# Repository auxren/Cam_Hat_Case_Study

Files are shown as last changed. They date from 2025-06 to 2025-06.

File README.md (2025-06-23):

# Raspberry Pi Zero 2 W Camera Module Daughterboard

## Overview

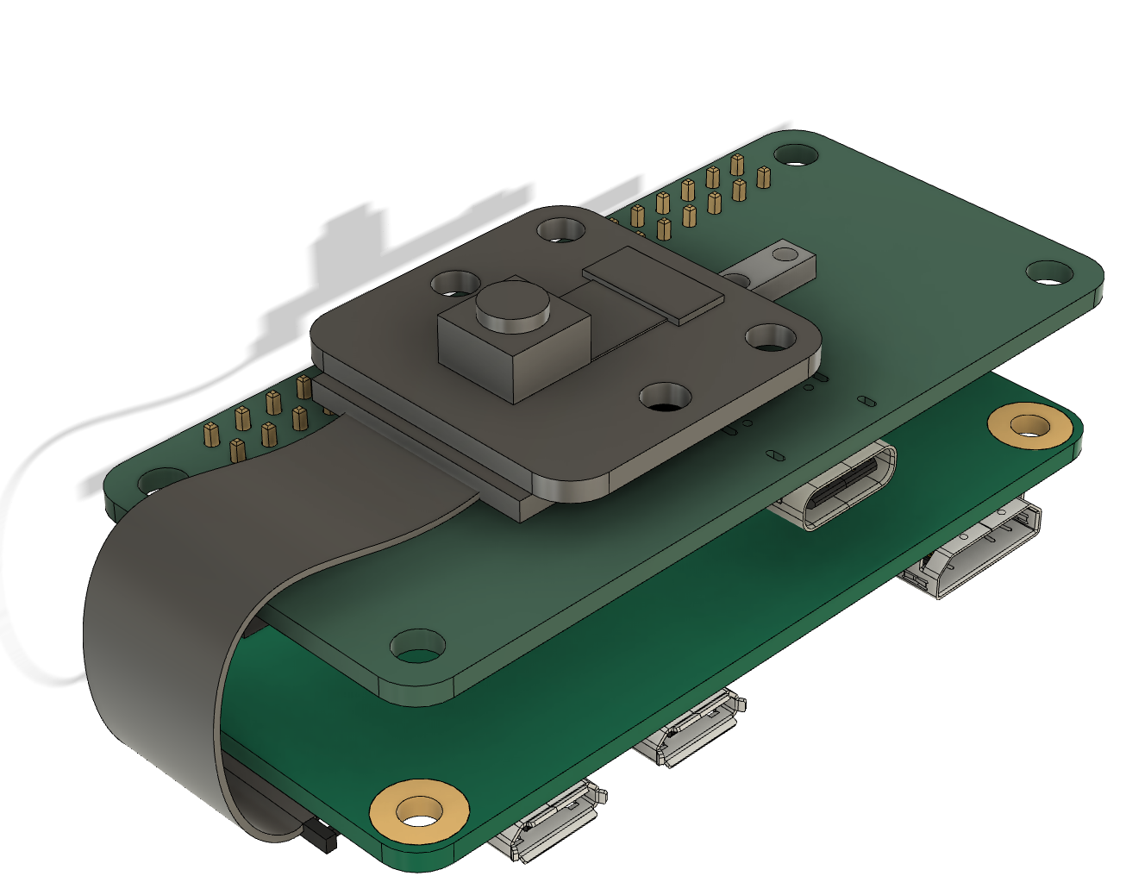
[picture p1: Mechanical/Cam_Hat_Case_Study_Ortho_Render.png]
RENDER


This was from a 72hr design challenge / case study for an interview for a Senior Electrical Engineering Role.

## Requirements

- Camera Module: Integrate the IMX219 camera module (IQL-IMX219/FF).
= Motion Detection: Integrate a suitable PIR motion sensor to detect motion to trigger the
camera.
- Lighting Adjustment: Integrate a suitable ambient light sensor that will be later used to
adjust camera settings based on lighting conditions.
- Power Supply: Design a power supply circuit to ensure stable operation. Choose and
justify the power management components used. Use at least one switching regulator in
your design.
- Form Factor: Ensure the daughter board fits within the dimensions of the Raspberry Pi
Zero 2 W (65mm x 30mm).
- Interconnection: The daughter board will connect to the Raspberry Pi Zero 2 W through
the GPIO header. All components, including the camera module, PIR sensor, and
ambient light sensor, must be placed on the daughter board. Additionally, include an FFC
connector on the edge of the daughter board to allow the user to connect an FFC cable
between the daughter board and the CSI interface of the Raspberry Pi Zero W.
- Power Supply: Assume the Raspberry Pi will be powered with a 5V 3A DC power
supply. Consider power losses and efficiencies.

## Features

- IMX219 camera integration via CSI interface  
- Ambient light sensor for lighting-aware imaging  
- PIR motion sensor to trigger camera events  
- Switching regulator-based power supply for high efficiency  
- Direct connection to the Raspberry Pi via GPIO and FFC  
- Test points and layout considerations for testability

## System Requirements

| Component | Specification |
|---|---|
| Camera Module | IMX219 (IQL-IMX219/FF) |
| PIR Sensor | Selected for compact form factor and reliable motion detection |
| Ambient Light Sensor | Tuned for visible spectrum and camera exposure control |
| Power Input | 5V 3A DC (via Raspberry Pi USB input) |
| Form Factor | 65mm x 30mm (same as Raspberry Pi Zero 2 W) |
| Interfaces | GPIO header and FFC connector |

## Deliverables

- ✅ Schematic Design (KiCad project and PDF)
- ✅ PCB Layout (KiCad, Gerber files, and 3D model)
- ✅ Bill of Materials (BOM) with part numbers and specifications
- ✅ Power Supply Design Document (efficiency and regulator choice justification)
- ✅ Design Decision Documentation (component selection and rationale)

## Folder Structure

<pre> <code>
├── Cam_Hat_Case_Study_Oren_Levy_Presentation.key -- Case study presentation. Open in Apple Keynote.
├── Cam_Hat_Case_Study_Oren_Levy_Presentation.pdf
├── Firmware:Software
│   └── TfH_Case_Study_FW_TODO.numbers -- Document for tracking items FW should be mindful of. Open in Apple Numbers.
├── Hardware
│   ├── Block Diagram
│   │   └── Cam_Hat_Case_Study_Block_Diagram.png -- High level block diagram
│   ├── BOMs
│   │   └── Cam_Hat_Case_Study_PCB_Assembly_BOM.csv -- Assembly BOM
│   ├── Datasheets -- Datasheet PDFs for referencing
│   ├── Pinout Docs
│   │   └── Cam_Hat_Case_Study_Pinout_Tracker.numbers -- Document for tracking pinouts and net names. Open in Apple Numbers.
│   ├── Power
│   │   └── CamHat_Power_Tracker.numbers -- Power calculator document. Open in Apple Numbers.
│   ├── Schematic
│   │   └── Cam_Hat_Case_Study_Schematic.pdf
│   └── TfH_Case_Study -- KiCad Project
├── LICENSE
├── Mechanical
│   ├── Cam_Hat_Case_Study_Model.STEP -- Model of full "product"
│   ├── Cam_Hat_Case_Study_Ortho_Render.png
│   ├── Cam_Hat_Case_Study_Render_Case_Ortho.png
│   ├── Cam_Hat_Case_Study_Side_Render.png
│   └── Subassemblies  -- Folder with dxf and stp files used for assembly
└── README.md
</code> </pre>

## Block Diagram
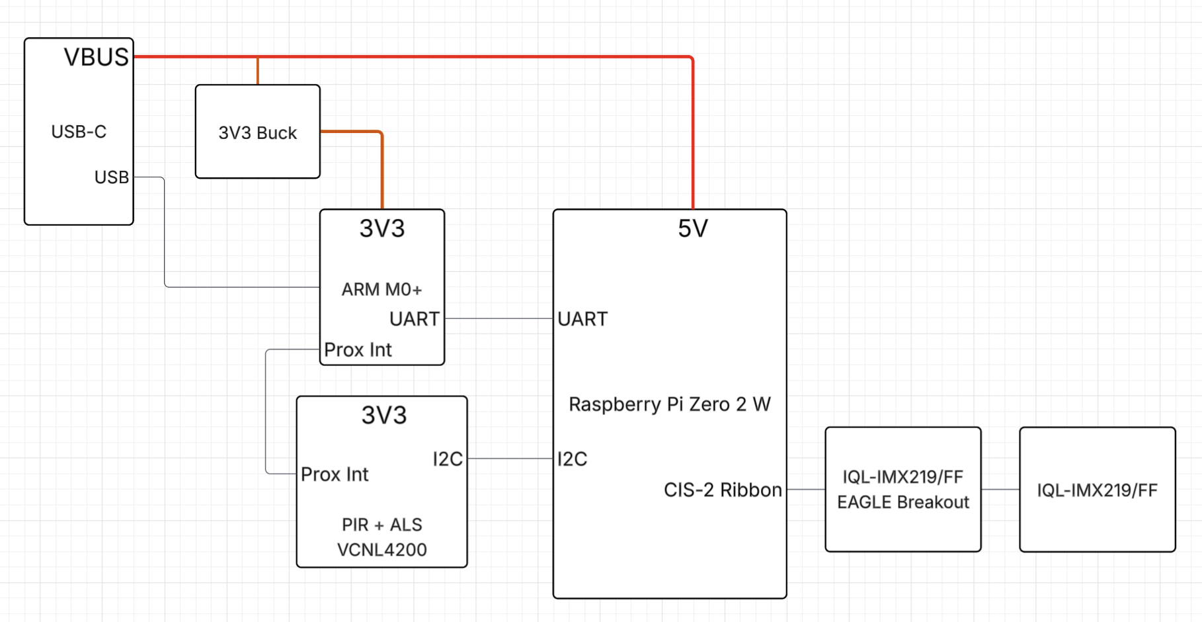
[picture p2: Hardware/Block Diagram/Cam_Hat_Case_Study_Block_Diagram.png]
BLOCK DIAGRAM


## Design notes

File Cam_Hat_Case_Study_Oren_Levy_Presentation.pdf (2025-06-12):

# Tools For Humanity Camera Hat Case Study

Prepared by Oren Levy

## Camera Hat | Intro & Renders

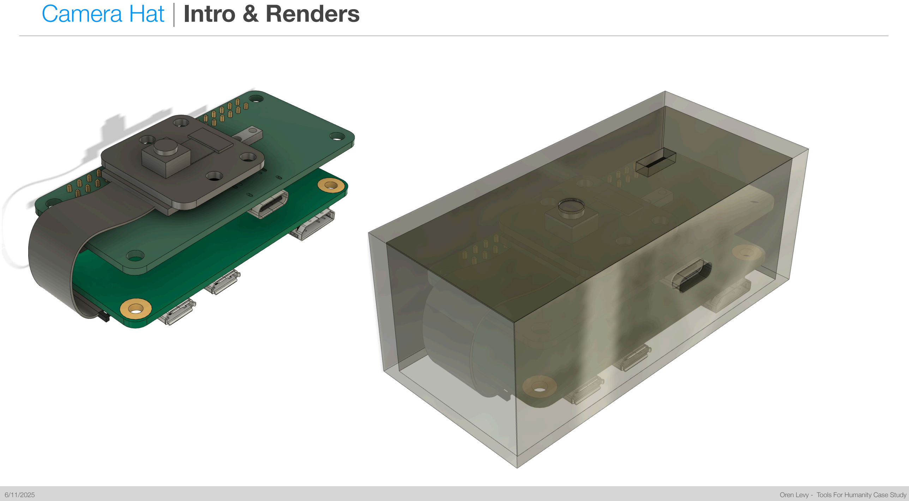
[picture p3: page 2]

6/11/2025 | Oren Levy - Tools For Humanity Case Study

## Camera Hat | Block Diagram

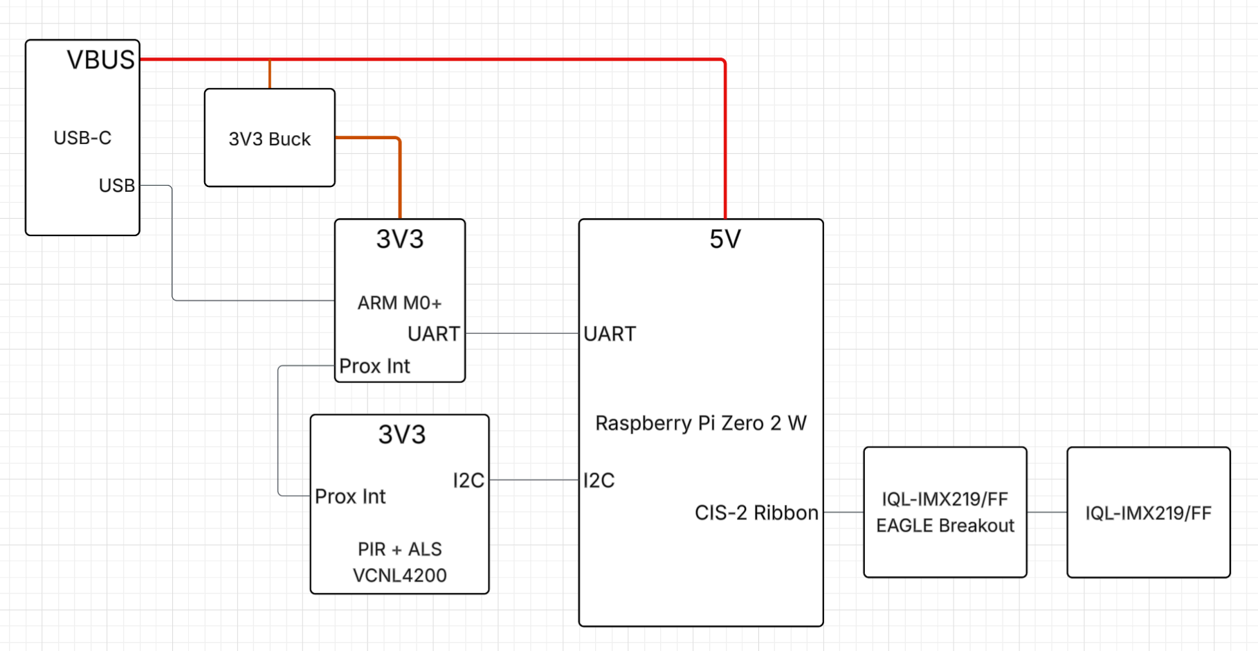
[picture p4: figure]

## Camera Hat | Features

- Arm M0+ incorporated
- Allows for 25mW standby consumption (Instead of 525mW) in conjunction with a load switch that disconnects the Raspberry Pi
- When motion is detected, an interrupt wakes up the MCU, which closes the load switch and boots (~6s). By using a longer distance (1.5 meter) proximity sensor, 6 seconds should be able time for the user to approach and position themselves in front of the camera.
- USB-C connector incorporated for application of power
- FATP test, debug, and firmware development to be done using USB-C connector
- Enumerates CLI, tunneling into Raspberry Pi via UART
- Disabled at end of FATP before packaging
- Vishay VCNL4200 used for Proximity and Ambient Light Sensing
- Initial research went into the recommended PIR sensors (slide). Cost and integration when incorporating an ALS grew in complexity. When comparing to a unit such as the VCNL4200 that combines the prox and ALS into a monolithic package (slide), the VCNL4200 won from a power, cost, and FATP integration point of view.
- A complex power architecture was conceived for powering the IQL-IMX219/FF. Upon further research, the IQL-IMX219/FF/Eagle (https://www.imagequalitylabs.com/digital-camera-modules/sony-imx219-8mp-ff-raspberry-pi-camera) was found. It adapts the IQL-IMX219/FF to the Raspberry Pi Zero 2 W’s CIS-2 ribbon connection. This alleviated any need for power rail generation, MIPI routing, and added complexity to the design; none of the camera signals touch the camera hat PCB.
- The IQL-IMX219/FF/Eagle (https://www.imagequalitylabs.com/digital-camera-modules/sony-imx219-8mp-ff-raspberry-pi-camera) mounts to the inside of the enclosure, the Camera Hat board goes on top, then the flex connects to the RPi, which gets plugged into the Camera Hat board.
- This left the necessity to generate a 3V3 rail via a buck converter, due to the case study’s requirements.
- The Raspberry Pi itself generates 3V3 with sufficient current to power the VCNL4200
- Factory testing at a PCBA level is enabled by TPs only on the bottom of the board, which only has the VCNL4200 as the only component, for easy fixturing in a bed of nails

## Camera Hat | Documents And Links

- Everything is shared on GitHub at: https://github.com/auxren/Cam_Hat_Case_Study/
- Schematic (https://github.com/auxren/Cam_Hat_Case_Study/blob/main/Hardware/Schematic/Cam_Hat_Case_Study_Schematic.pdf)
- KiCad Project (https://github.com/auxren/Cam_Hat_Case_Study/tree/main/Hardware/TfH_Case_Study)
- BOM (https://github.com/auxren/Cam_Hat_Case_Study/blob/main/Hardware/BOMs/Cam_Hat_Case_Study_PCB_Assembly_BOM.csv)
- Power Calculator (https://github.com/auxren/Cam_Hat_Case_Study/blob/main/Hardware/Power/CamHat_Power_Tracker.numbers)

# Design Considerations

## Camera Hat | PIR Sensor: Downselection

MPN | Manufacturer | Voltage | Current | IO | Range | FOV | Cost | Size | Notes
EKMB1110112 | Panasonic | 2.3-4V

1uA Sleep
1.9uA
Standy
100uA Max
Drive
Digital | 5m | 100° × 90° | $12.22@5
00 | 10.6 x 10.6 x 10.9 | Black
Rectangle
EKMB110711* | Panasonic | 2.3-4V

1uA Sleep
1.9uA
Standy
100uA Max
Drive
Digita | 5m | 100° × 90° | $12.51@5
| | | 00

10.4mm dia
10.9mm tall

White or
Black Dome
IRA-S210ST01 | Murata | 2.7-3.6V | ~6uA | Analog | 3m | 100° × 90° | $1.3@500 | 12 x 7 x 5

Cheaper
because it
doesn’t
include lease.
Analog

## Camera Hat | PIR Vs Combo PIR+ALS: Downselection

MPN | Manufacturer | Voltage | Current | IO | Range | FOV | Cost | Size | Notes
EKMB1110112 | Panasonic | 2.3-4V

1uA Sleep
1.9uA Standy
100uA Max
Digital | 5m | 100° × 90° | $12.22@500 | 10.6 x 10.6 x 10.9

Prox Only
Black
Rectangle
LTR-578ALS-01 | Liteon | 1.7-3.6V

1uA Standby
95uA Prox
110uA ALS

I2C
INT | 10cm | - | $0.42@100 | 3.9 x 2.36 x 1.35

Combo Prox
and ALS
Short
Distance
VCNL4040M3OE | Vishay | 2.5-3.6

300uA + LED
Active
460uA Shut
Down
I2C | 20cm | ~40° | $1.20@500 | 4 x 2 x 1.1

Combo Prox
and ALS
Short
Distance
VCNL4200 | Vishay | 2.5-3.6

0.2uA Sleep
213uA Prox
350uA max +
LED
I2C | 1.5m | ~40° | $1.51@5,000 | 8 x 3 x 1.8 | Combo Prox and ALS

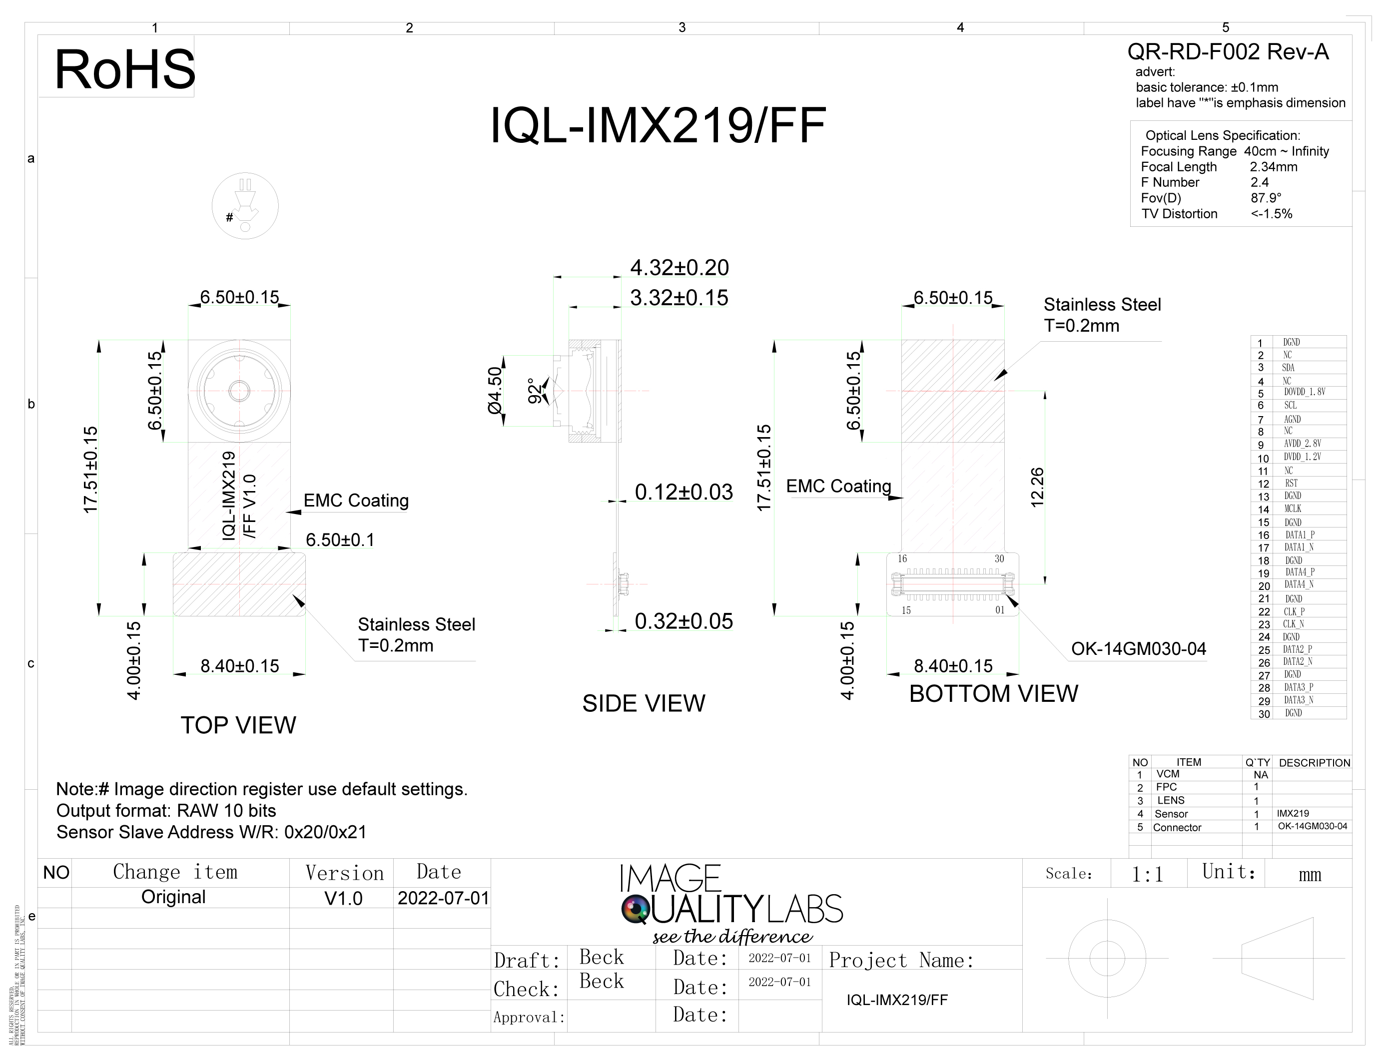
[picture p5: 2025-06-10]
Hardware/Datasheets/IQL-IMX219:FF/666b24bf9f3bf878a5250962_IQL-IMX219-FF-Latest_Drawing.jpg

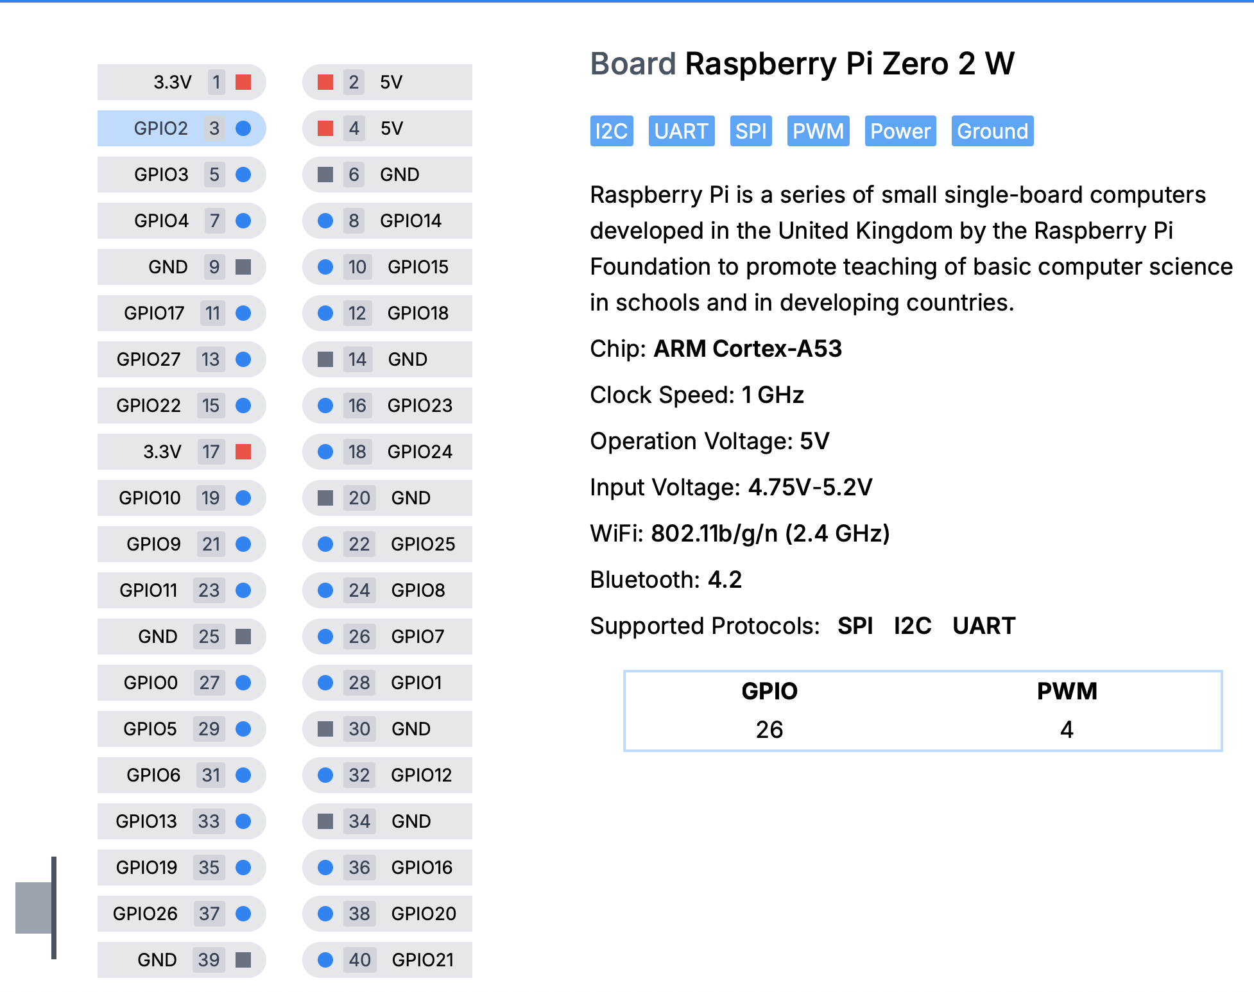
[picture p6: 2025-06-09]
Hardware/Datasheets/RPi Zero 2 W/RPiZero2W Pinout.png

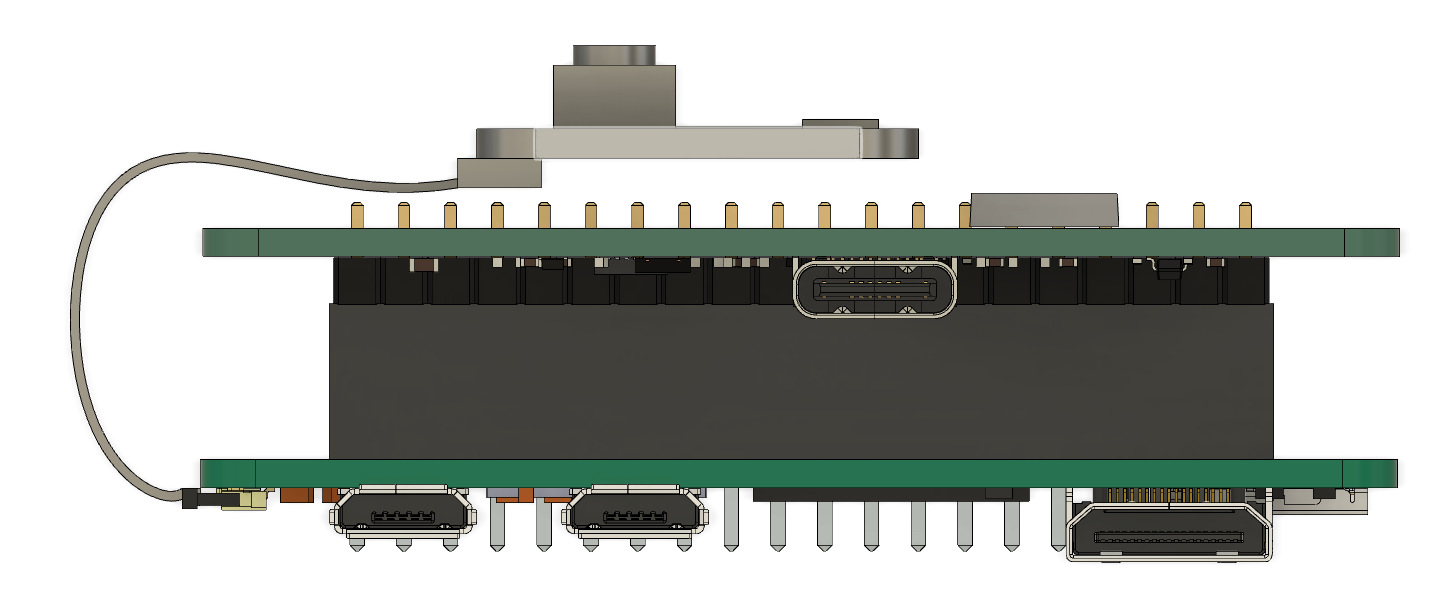
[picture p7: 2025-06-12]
Mechanical/Cam_Hat_Case_Study_Side_Render.png

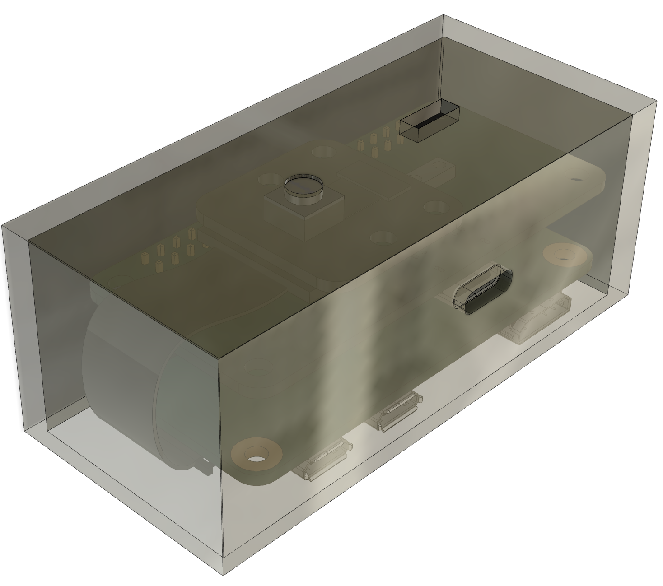
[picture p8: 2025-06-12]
Mechanical/Cam_Hat_Case_Study_Render_Case_Ortho.png

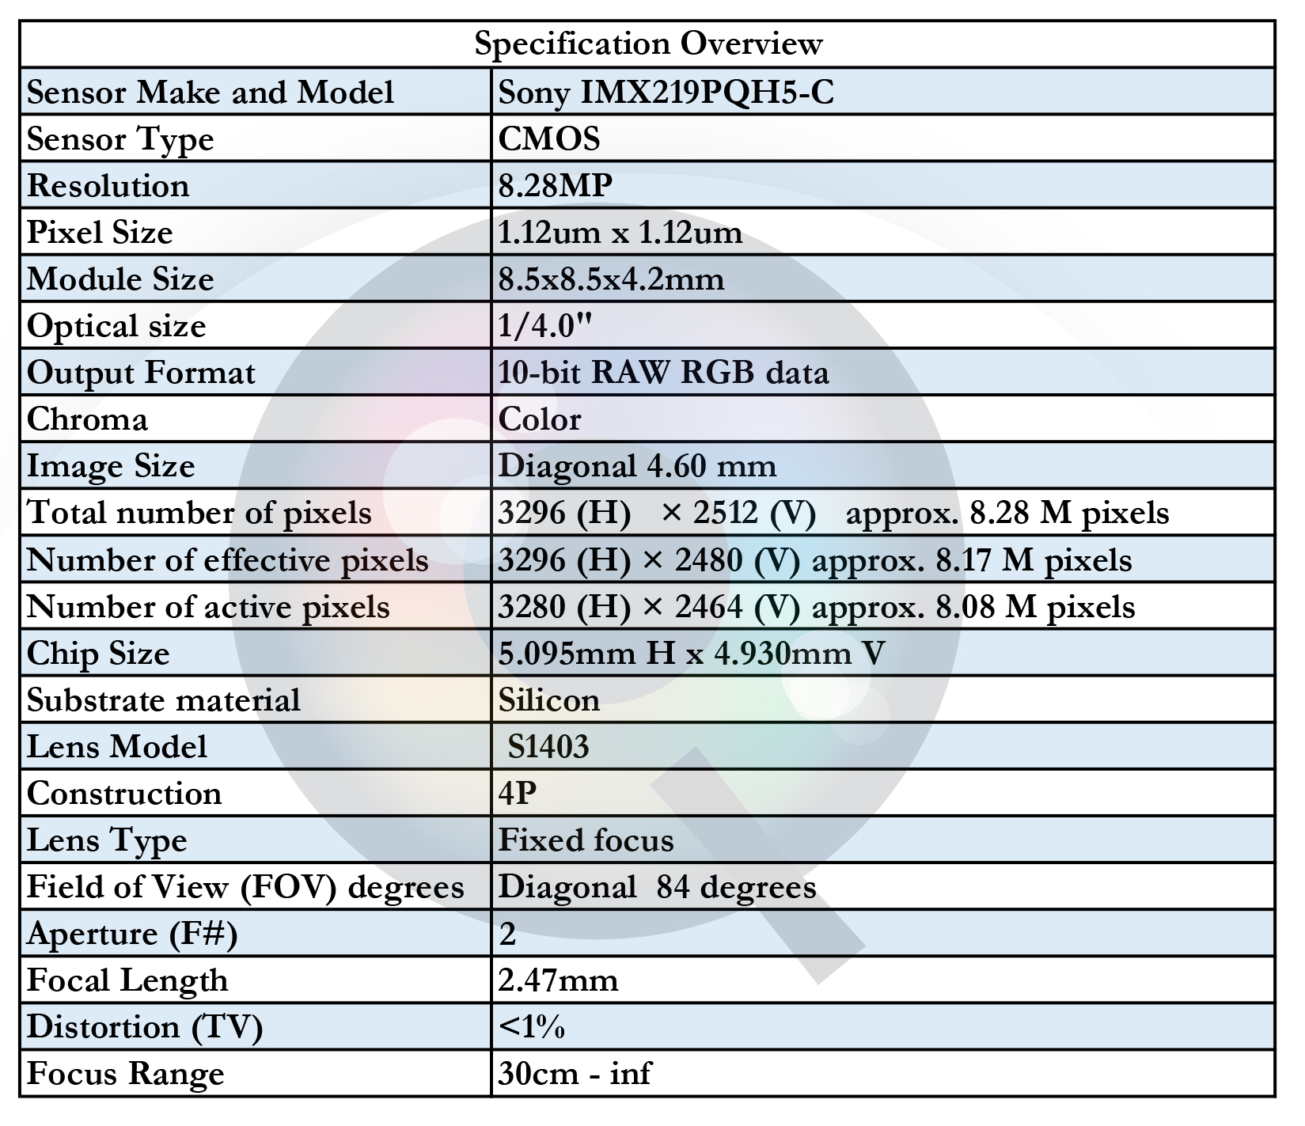
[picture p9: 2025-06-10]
Hardware/Datasheets/IQL-IMX219:FF/68388aef5e7ae0aa4206bc80_643aabf46146708020343a5a_IMX219FF%20Table.jpeg

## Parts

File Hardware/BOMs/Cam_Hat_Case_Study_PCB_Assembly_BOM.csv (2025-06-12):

Reference | Qty | Value | DNP | Footprint | Datasheet | Manufacturer_Name | Manufacturer_Part_Number | Description
C201,C303 | 2 | 22uF |  | Capacitor_SMD:C_0402_1005Metric | ~ | Murata | GRM158R61A226ME15J | Multilayer Ceramic Capacitors MLCC - SMD/SMT 22 uF 10 VDC 20% 0402 X5R
C202 | 1 | 1uF |  | Capacitor_SMD:C_0402_1005Metric | ~ | Kyocera | 04023D105KAT2A
C301,C601,C603 | 3 | 4.7uF |  | Capacitor_SMD:C_0402_1005Metric | ~ | Kyocera | 0402YD475MAT2A | Multilayer Ceramic Capacitors MLCC - SMD/SMT KGM05CR51C475MH NEW GLOBAL PN 16V 4.7uF A 581-KGM05CR51C475MH
C401 | 1 | 100uF |  | Capacitor_SMD:C_0805 | ~ | Kyocera | 08056D107MAT2A | Multilayer Ceramic Capacitors MLCC - SMD/SMT KGM21AR50J107MU NEW GLOBAL PN 6.3V 100uF A 581-KGM21AR50J107MU
C402 | 1 | 10uF |  | Capacitor_SMD:C_0603_1608Metric | ~ | Kyocera | 0603YD106MAT2A | Multilayer Ceramic Capacitors MLCC - SMD/SMT KGM15CR51C106MT NEW GLOBAL PN A 581-KGM15CR51C106MT
C502 | 1 | 2.2uF |  | Capacitor_SMD:C_0402_1005Metric | ~ | Kyocera | 0402ZD225MAT2A | Multilayer Ceramic Capacitors MLCC - SMD/SMT KGM05AR51A225MH NEW GLOBAL PN 10V 2.2uF A 581-KGM05AR51A225MH
C602,C604,C403,C501 | 4 | 100nF |  | Capacitor_SMD:C_0402_1005Metric | ~ | Kyocera | 0402X7R104KT7AT | Multilayer Ceramic Capacitors MLCC - SMD/SMT 16V 0.1uF X7R 10%
D601 | 1 | PESD5V0S1UL |  | Diode_SMD:D_SOD-882 | https://assets.nexperia.com/documents/data-sheet/PESD5V0S1UL.pdf | Nexperia | PESD5V0S1UL | Unidirectional ESD protection diode, 5V, SOD-882
FB601,FB602 | 2 | FerriteBead |  | Capacitor_SMD:C_0402_1005Metric | ~ | TDK | MPZ1005S330HT000 | Ferrite Beads 33OHM 3a 22mohms 1005 FERRITE CHIP
IC201 | 1 | TPS22969DNYT |  | TPS22969DNYT | http://www.ti.com/lit/gpn/TPS22969 | Texas Instruments | TPS22969DNYT | 5.5V, 6A, 4.4m Load Switch with Quick Output Discharge
IC601 | 1 | ATSAMD11D14A-MUT |  | Footprints:QFN50P400X400X90-25N-D | https://datasheet.datasheetarchive.com/originals/distributors/DKDS41/DSANUWW0026705.pdf | Microchip | ATSAMD11D14A-MUT | ARM Microcontrollers - MCU IC MCU 32 BIT 16KB Flash 24QFN
J601 | 1 | USB_C_Receptacle_USB2.0_14P |  | Connector_USB:USB_C_Receptacle_GCT_USB4105-xx-A_16P_TopMnt_Horizontal | https://www.usb.org/sites/default/files/documents/usb_type-c.zip | Same Sky | UJ32-C-H-G-SMT-6-P24-TR | USB Connectors Type C, 3.2, Horizontal, Gold Flash, Surface Mount, 24 pin, T&R
L301 | 1 | 1uH |  | Inductor_SMD:L2x1_6 | ~ | Murata | LQM2HPN1R0MG0 | 1.0 µH, 1.9 A Isat, 33 mΩ DCR
Q501 | 1 | Si2319CDS |  | Package_TO_SOT_SMD:SOT-23 | http://www.vishay.com/docs/66709/si2319cd.pdf | Vishay | Si2319CDS | -4.4A Id, -40V Vds, P-Channel MOSFET, SOT-23
R302,R310,R312,R314,R402,R403,R405 | 7 | 0Ω 0402 |  | Resistor_SMD:R_0402_1005Metric | ~ | Vishay | CRCW04020000Z0EDC | Thick Film Resistors - SMD 1/16watt 0ohm Commercial Use
R304 | 1 | 453k |  | Resistor_SMD:R_0402_1005Metric | ~ | Vishay | CRCW0402453KFKTD | Thick Film Resistors - SMD 1/16watt 453Kohms 1%
R305 | 1 | 100k |  | Resistor_SMD:R_0402_1005Metric | ~ | Panasonic | ERJ-S02J104X | Thick Film Resistors - SMD 0402 100Kohms 1%
R319 | 1 | 0Ω 0402 | DNP | Resistor_SMD:R_0402_1005Metric | ~ | Vishay | CRCW04020000Z0EDC | Thick Film Resistors - SMD 1/16watt 0ohm Commercial Use
R401,R404 | 2 | 3.3k 0402 |  | Resistor_SMD:R_0402_1005Metric | ~ | Yageo | RC0402FR-7D3K3L | Thick Film Resistors - SMD 0402 3.3Kohms 1%
R501 | 1 | 2.7k 0402 |  | Resistor_SMD:R_0402_1005Metric | ~ | Panasonic | ERA-2ARC272X | Thin Film Resistors - SMD 0402 Thin film chip resistor
R502 | 1 | 1k 0402 |  | Resistor_SMD:R_0402_1005Metric | ~ | SEI Stackpole | RNCE0402BTE1K00 | Thin Film Resistors - SMD 1KOhms 0402 25ppm 1/16W 50V 0.1% Hi Temp/Stability
R601,R602 | 2 | 5.1k 0402 |  | Resistor_SMD:R_0402_1005Metric | ~ | Kamaya | RMC1/16SK5111FTH | Thick Film Resistors - SMD 0402 5K11 1%
U301 | 1 | TLV62568ADRL |  | Package_TO_SOT_SMD:SOT-563 | https://www.ti.com/lit/gpn/tlv62568a | Texas Instruments | TLV62568ADRL | High Efficiency Synchronous Buck Converter with forced PWM, Adjustable Output 0.6V-5.5V, 1A, SOT-563-6
U401 | 1 | Raspberry Pi Zero 2 W |  | Connector_PinHeader_2.54mm:PinHeader_2x20_P2.54mm_Vertical |  | Molex | 90131-0780 | Headers & Wire Housings 2.54MM CGRIDIII HDR 40P VERT DR SEL AU
U501 | 1 | VCNL4200 |  | Footprints:SMT_L4200_VIS | VCNL4200 | Vishay | VCNL4200 | High Sensitivity Long Distance Proximity and Ambient Light Sensor With I2C Interface
U601 | 1 | TPD4E05U06DQA |  | Package_SON:USON-10_2.5x1.0mm_P0.5mm | https://www.ti.com/lit/ds/symlink/tpd4e05u06.pdf | Texas Instruments | TPD4E05U06DQA | 4-Channel ESD Protection for Super-Speed USB 3.0 Interface, USON-10

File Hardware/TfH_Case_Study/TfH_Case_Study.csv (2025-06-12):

Reference | Qty | Value | DNP | Exclude from BOM | Exclude from Board | Footprint | Datasheet | Manufacturer_Name | Manufacturer_Part_Number | Mouser Part Number | Description
C201,C303 | 2 | 22uF |  |  |  | Capacitor_SMD:C_0402_1005Metric | ~
C202 | 1 | 1uF |  |  |  | Capacitor_SMD:C_0402_1005Metric | ~
C301,C601,C603 | 3 | 4.7uF |  |  |  | Capacitor_SMD:C_0402_1005Metric | ~ |  |  |  | Unpolarized capacitor
C401 | 1 | 100uF |  |  |  | Capacitor_SMD:C_0603_1608Metric | ~ |  |  |  | Unpolarized capacitor, small symbol
C402 | 1 | 10uF |  |  |  | Capacitor_SMD:C_0603_1608Metric | ~ |  |  |  | Unpolarized capacitor, small symbol
C403,C501 | 2 | 0.1uF |  |  |  | Capacitor_SMD:C_0402_1005Metric | ~
C502 | 1 | 2.2uF |  |  |  | Capacitor_SMD:C_0402_1005Metric | ~
C602,C604 | 2 | 100nF |  |  |  | Capacitor_SMD:C_0402_1005Metric | ~ |  |  |  | Unpolarized capacitor
D601 | 1 | PESD5V0S1UL |  |  |  | Diode_SMD:D_SOD-882 | https://assets.nexperia.com/documents/data-sheet/PESD5V0S1UL.pdf |  |  |  | Unidirectional ESD protection diode, 5V, SOD-882
FB601,FB602 | 2 | FerriteBead |  |  |  | Capacitor_SMD:C_0402_1005Metric | ~
H1,H2,H4,H5 | 4 | MountingHole_Pad |  | Excluded from BOM |  | MountingHole:MountingHole_3.2mm_M3_DIN965_Pad | ~ |  |  |  | Mounting Hole with connection
IC201 | 1 | TPS22969DNYT |  |  |  | TPS22969DNYT | http://www.ti.com/lit/gpn/TPS22969 | Texas Instruments | TPS22969DNYT | 595-TPS22969DNYT | 5.5V, 6A, 4.4m Load Switch with Quick Output Discharge
IC601 | 1 | ATSAMD11D14A-MUT |  |  |  | Footprints:QFN50P400X400X90-25N-D | https://datasheet.datasheetarchive.com/originals/distributors/DKDS41/DSANUWW0026705.pdf | Microchip | ATSAMD11D14A-MUT | 556-ATSAMD11D14A-MUT | ARM Microcontrollers - MCU IC MCU 32 BIT 16KB Flash 24QFN
J601 | 1 | USB_C_Receptacle_USB2.0_14P |  |  |  | Connector_USB:USB_C_Receptacle_GCT_USB4105-xx-A_16P_TopMnt_Horizontal | https://www.usb.org/sites/default/files/documents/usb_type-c.zip |  |  |  | USB 2.0-only 14P Type-C Receptacle connector
J602 | 1 | Conn_ARM_JTAG_SWD_10 |  |  |  | Connector_PinHeader_1.00mm:PinHeader_2x05_P1.00mm_Vertical_SMD | http://infocenter.arm.com/help/topic/com.arm.doc.ddi0314h/DDI0314H_coresight_components_trm.pdf |  |  |  | Cortex Debug Connector, standard ARM Cortex-M SWD and JTAG interface
L301 | 1 | 1uH |  |  |  | Capacitor_SMD:C_0402_1005Metric | ~
Q501 | 1 | Si2319CDS |  |  |  | Package_TO_SOT_SMD:SOT-23 | http://www.vishay.com/docs/66709/si2319cd.pdf |  |  |  | -4.4A Id, -40V Vds, P-Channel MOSFET, SOT-23
R302,R310,R312,R314,R402,R403,R405 | 7 | 0 |  |  |  | Capacitor_SMD:C_0402_1005Metric | ~
R304 | 1 | 453k |  |  |  | Capacitor_SMD:C_0402_1005Metric | ~
R305 | 1 | 100k |  |  |  | Capacitor_SMD:C_0402_1005Metric | ~
R319 | 1 | 0 | DNP |  |  | Capacitor_SMD:C_0402_1005Metric | ~
R401,R404 | 2 | 3.3k |  |  |  | Capacitor_SMD:C_0402_1005Metric | ~
R501 | 1 | 2.7k |  |  |  | Resistor_SMD:R_0402_1005Metric | ~ |  |  |  | Resistor, US symbol
R502 | 1 | 1k |  |  |  | Resistor_SMD:R_0402_1005Metric | ~ |  |  |  | Resistor, US symbol
R601,R602 | 2 | 5.1 k |  |  |  | Resistor_SMD:R_0402_1005Metric | ~ |  |  |  | Resistor, US symbol
TP401,TP402,TP403,TP501,TP502,TP503,TP504,TP505,TP506,TP507,TP508,TP509,TP510,TP601,TP602,TP603,TP604,TP605,TP606,TP607,TP608,TP609,TP610 | 23 | TestPoint |  | Excluded from BOM |  | TestPoint:TestPoint_Pad_D1.5mm | ~ |  |  |  | test point
U301 | 1 | TLV62568ADRL |  |  |  | Package_TO_SOT_SMD:SOT-563 | https://www.ti.com/lit/gpn/tlv62568a |  |  |  | High Efficiency Synchronous Buck Converter with forced PWM, Adjustable Output 0.6V-5.5V, 1A, SOT-563-6
U401 | 1 | Raspberry Pi Zero 2 W |  |  |  | Connector_PinHeader_2.54mm:PinHeader_2x20_P2.54mm_Vertical
U501 | 1 | VCNL4200 |  |  |  | Footprints:SMT_L4200_VIS | VCNL4200
U601 | 1 | TPD4E05U06DQA |  |  |  | Package_SON:USON-10_2.5x1.0mm_P0.5mm | https://www.ti.com/lit/ds/symlink/tpd4e05u06.pdf |  |  |  | 4-Channel ESD Protection for Super-Speed USB 3.0 Interface, USON-10

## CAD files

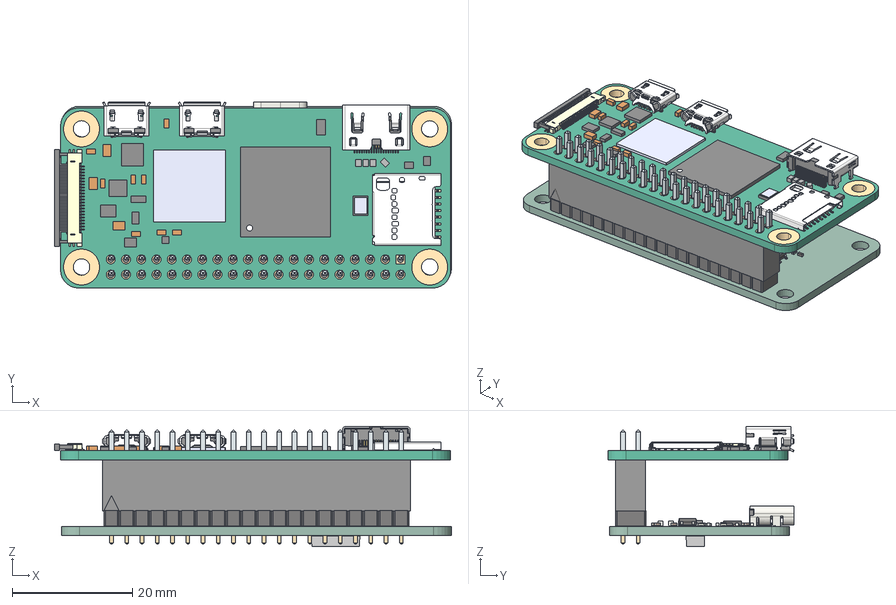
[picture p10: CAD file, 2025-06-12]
Hardware/TfH_Case_Study/Cam_Hat_Case_Study_Model.STEP
66.1 x 31.0 x 20.0 mm
C_0402_1005Metric x 26
R_0402_1005Metric x 4
ThermalPin
PinsArrayLR
PinsArrayTB
PinHeader_2x20_P2.54mm_Vertical
pcb
BCM 2835
ram
Part1^RASPBERRY PI ZERO 2 W
LeadsArray
C_0603_1608Metric x 2
SOT-23
SOT-563
D_SOD-882
USON-10_2.5x1.0mm_P0.5mm
USB_C_Receptacle_GCT_USB4105-xx-A_16P_TopMnt_Horizontal
Prox
TfH_Case_Study_PCB

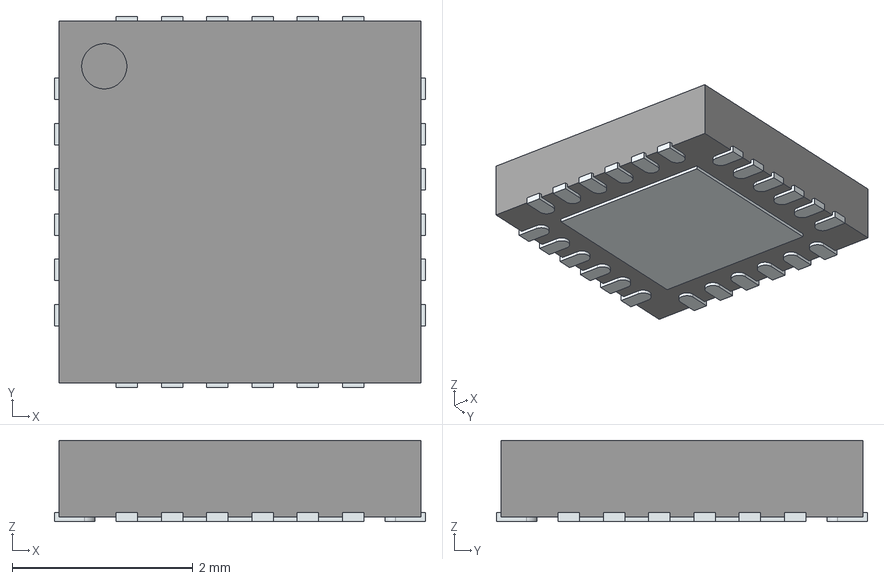
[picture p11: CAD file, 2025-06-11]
Hardware/TfH_Case_Study/Symbols_Footprints/LIB_ATSAMD11D14A-MUT/ATSAMD11D14A-MUT/3D/ATSAMD11D14A-MUT.stp
4.10 x 4.10 x 0.9 mm
ThermalPin
PinsArrayLR
PinsArrayTB

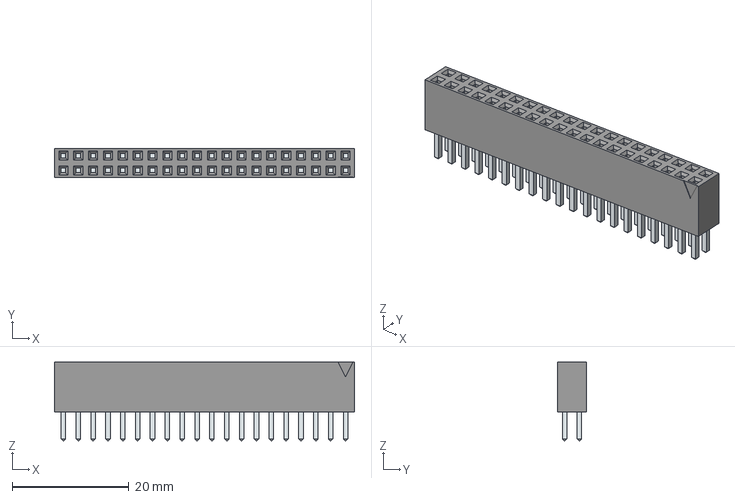
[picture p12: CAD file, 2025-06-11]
Hardware/TfH_Case_Study/Symbols_Footprints/LIB_SSW-120-02-G-D/SSW-120-02-G-D/3D/SSW-120-02-G-D.stp
51.3 x 4.95 x 13.4 mm
LeadsArray

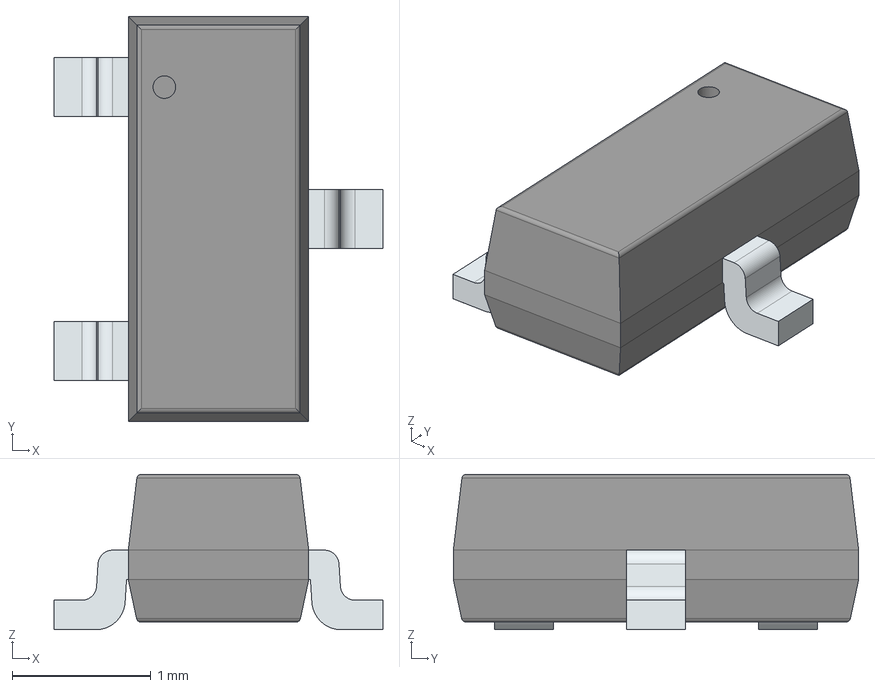
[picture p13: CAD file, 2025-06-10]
Hardware/TfH_Case_Study/Symbols_Footprints/SI2301CDS-T1-BE3.stp
2.37 x 2.92 x 1.12 mm
PinsArrayL
FilletPinR

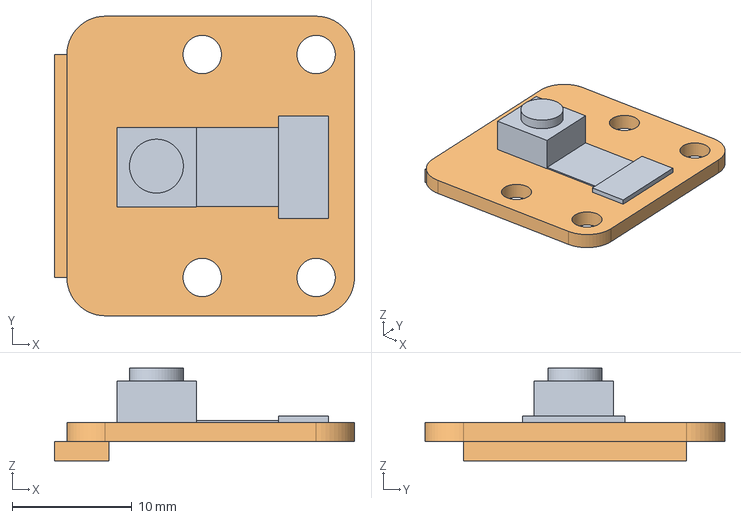
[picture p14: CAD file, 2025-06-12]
Mechanical/Subassemblies/CameraModuleOnEagle.step
25.0 x 25.0 x 7.72 mm

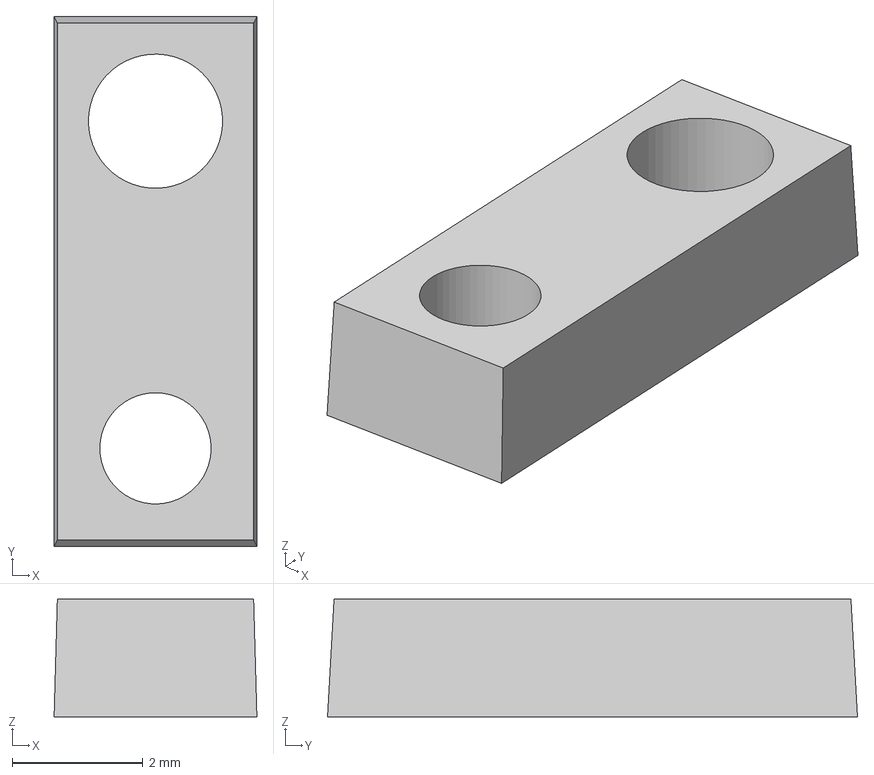
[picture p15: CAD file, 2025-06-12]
Mechanical/Subassemblies/Prox.step
3.10 x 8.10 x 1.80 mm

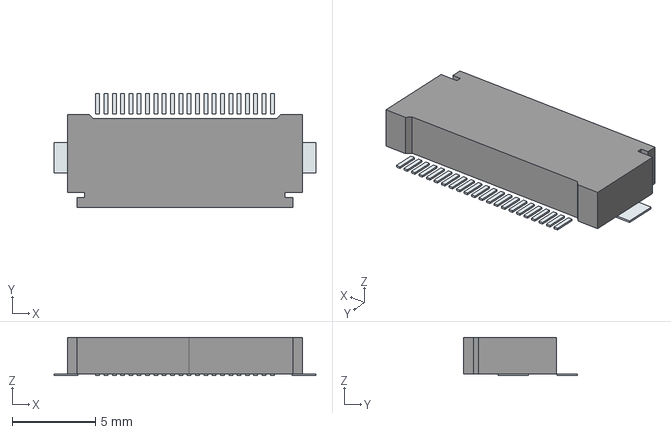
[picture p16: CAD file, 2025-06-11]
Hardware/TfH_Case_Study/Symbols_Footprints/Footprints/FH12-22S-0.5SH_1__98_.stp
15.7 x 6.87 x 2.30 mm
Pins

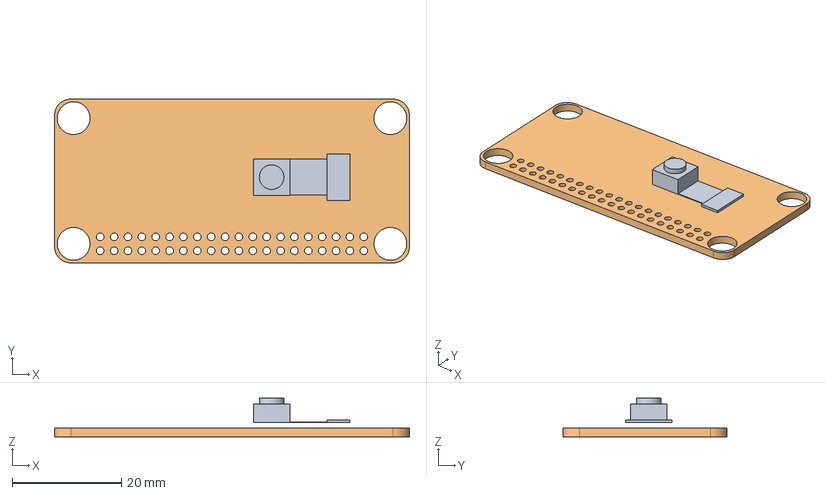
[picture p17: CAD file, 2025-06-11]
Mechanical/Subassemblies/CapHat v3.step
65.0 x 30.0 x 7.12 mm

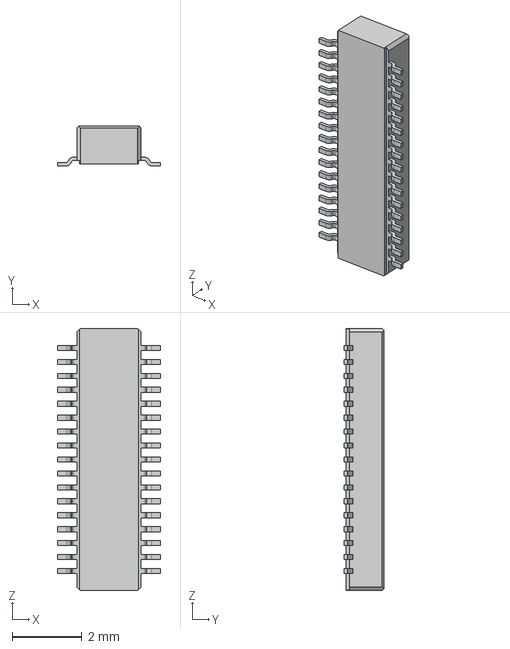
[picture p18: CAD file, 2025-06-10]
Hardware/TfH_Case_Study/Symbols_Footprints/Footprints/DF40C-30DP-0.4V_51_.stp
2.97 x 1.14 x 7.52 mm

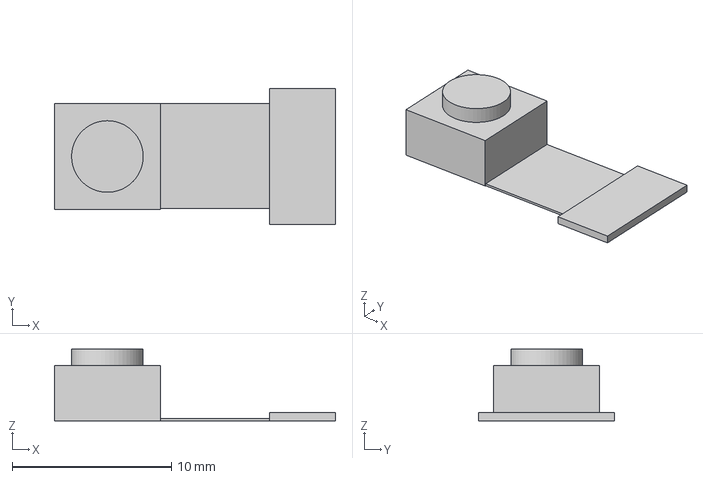
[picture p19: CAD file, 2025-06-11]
Mechanical/Subassemblies/CameraV1.step
17.7 x 8.55 x 4.52 mm

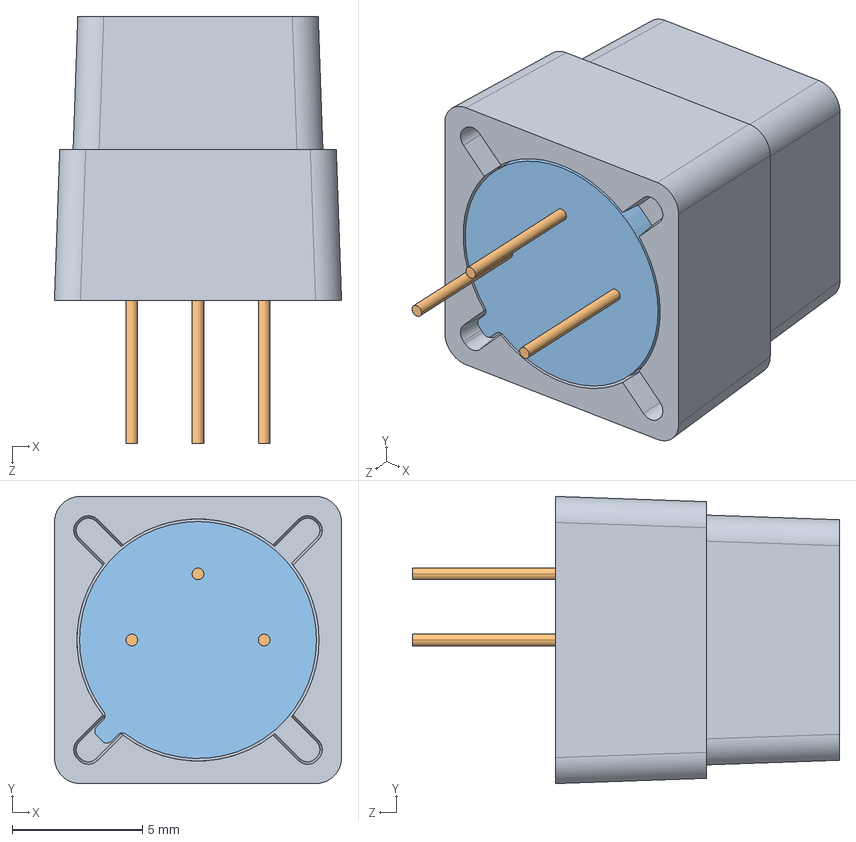
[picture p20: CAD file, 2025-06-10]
Hardware/TfH_Case_Study/Symbols_Footprints/Footprints/EKMB1110112.stp
11.0 x 11.0 x 16.4 mm
(Temp)PaPIRs Flat square type lens_蹬怮椔
stem_蹬怮椔

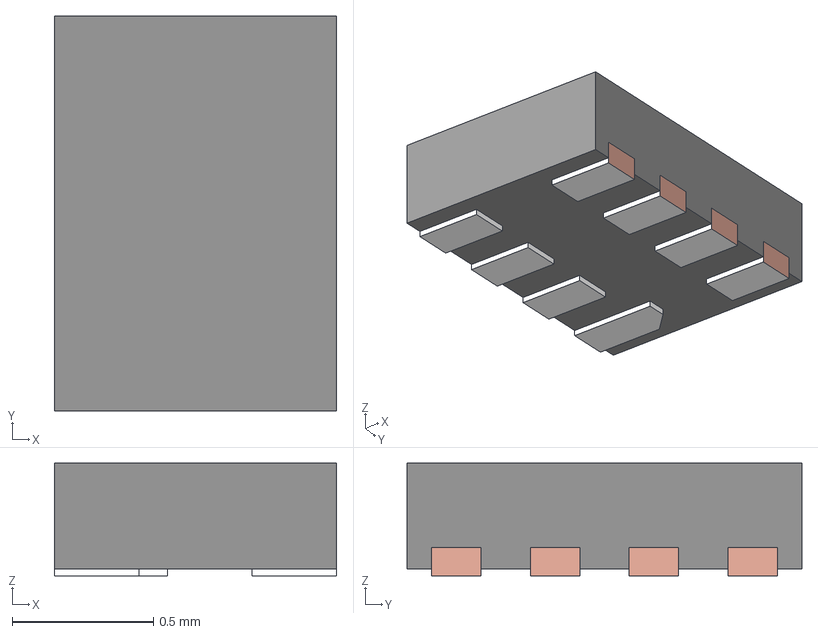
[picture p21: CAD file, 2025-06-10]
Hardware/TfH_Case_Study/Symbols_Footprints/Footprints/PCA9306DQER.stp
1.00 x 1.40 x 0.4 mm
BODY-SON1
FRAME-DQE0008A

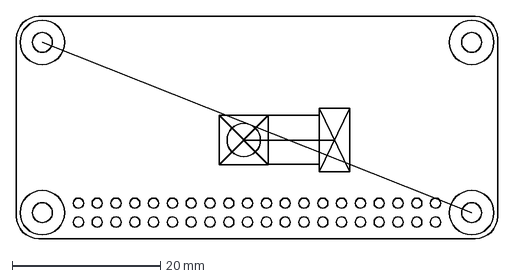
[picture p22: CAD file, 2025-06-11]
Mechanical/Subassemblies/CapHat v4.dxf
65.0 x 30.0 mm

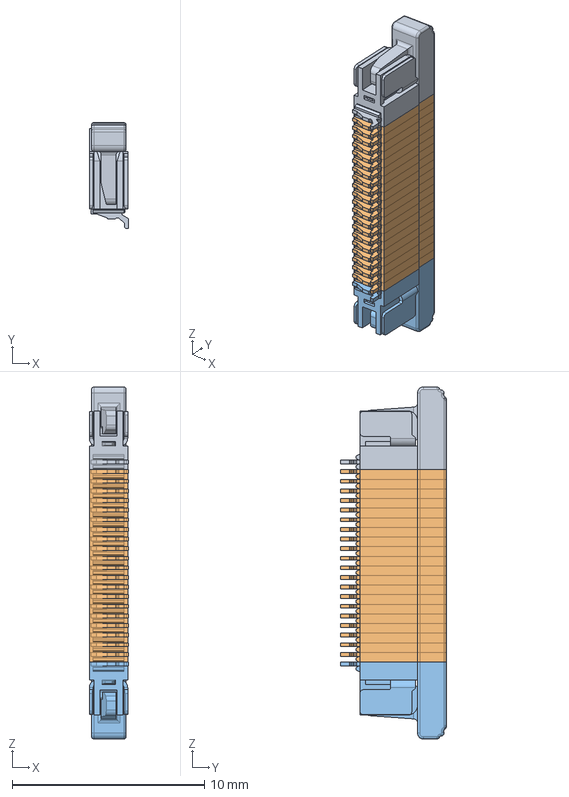
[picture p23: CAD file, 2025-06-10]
Hardware/TfH_Case_Study/Symbols_Footprints/Footprints/F32Q-1A7H1-11022.stp
2.05 x 5.50 x 18.3 mm
F32Q_L
F32Q_M x 20
F32Q_R

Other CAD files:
Mechanical/Subassemblies/CapHat_MCO_V1.dxf
Hardware/TfH_Case_Study/Symbols_Footprints/Footprints/TPS22969DNYT.stp
Hardware/TfH_Case_Study/Symbols_Footprints/LIB_ATSAMD11D14A-MUT/ATSAMD11D14A-MUT/Allegro/qfn50p400x400x90-25n-d.psm
Hardware/TfH_Case_Study/Symbols_Footprints/LIB_ATSAMD11D14A-MUT/ATSAMD11D14A-MUT/DEHDL/atsamd11d14a_mut/chips/chips.prt
Hardware/TfH_Case_Study/Symbols_Footprints/LIB_SI2301CDS-T1-BE3/SI2301CDS-T1-BE3/Allegro/sot95p237x112-3n.psm
Hardware/TfH_Case_Study/Symbols_Footprints/LIB_SI2301CDS-T1-BE3/SI2301CDS-T1-BE3/DEHDL/si2301cds_t1_be3/chips/chips.prt
Hardware/TfH_Case_Study/Symbols_Footprints/LIB_SSW-120-02-G-D/SSW-120-02-G-D/Allegro/rhdr40w79p254_2x20_5131x495x851p.psm
Hardware/TfH_Case_Study/Symbols_Footprints/LIB_SSW-120-02-G-D/SSW-120-02-G-D/DEHDL/ssw_120_02_g_d/chips/chips.prt
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

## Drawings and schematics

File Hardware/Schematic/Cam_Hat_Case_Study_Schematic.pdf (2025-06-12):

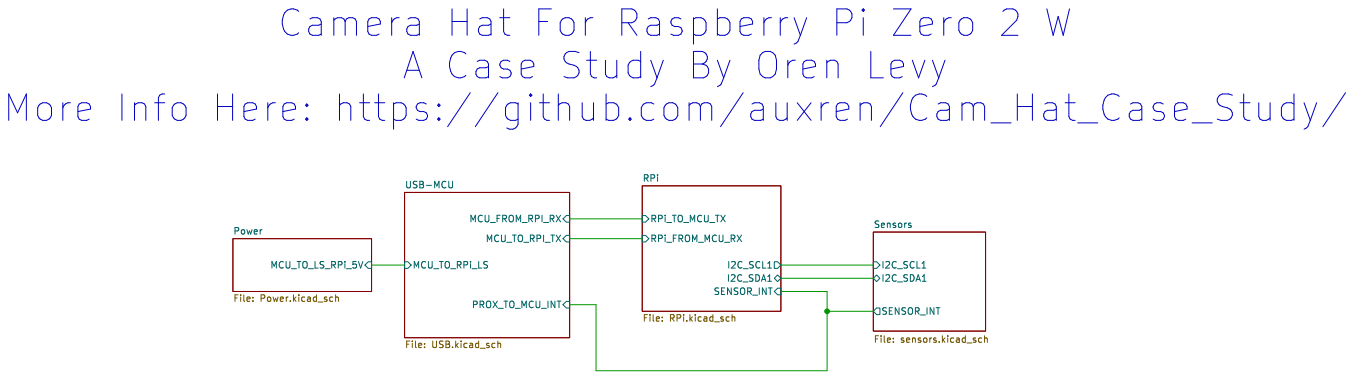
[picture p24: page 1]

Id: 1/5 Title: File: TfH_Case_Study.kicad_sch Sheet: /

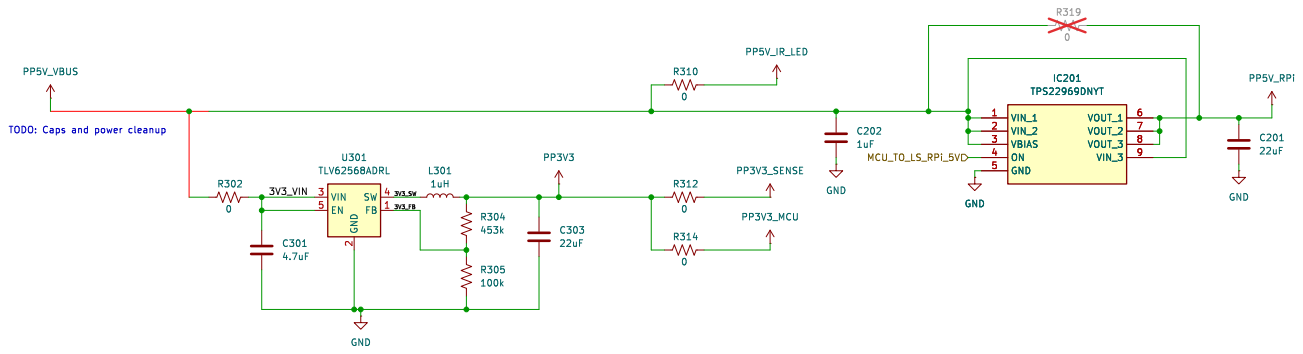
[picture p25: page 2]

Id: 3/5 Title: File: Power.kicad_sch Sheet: /Power/

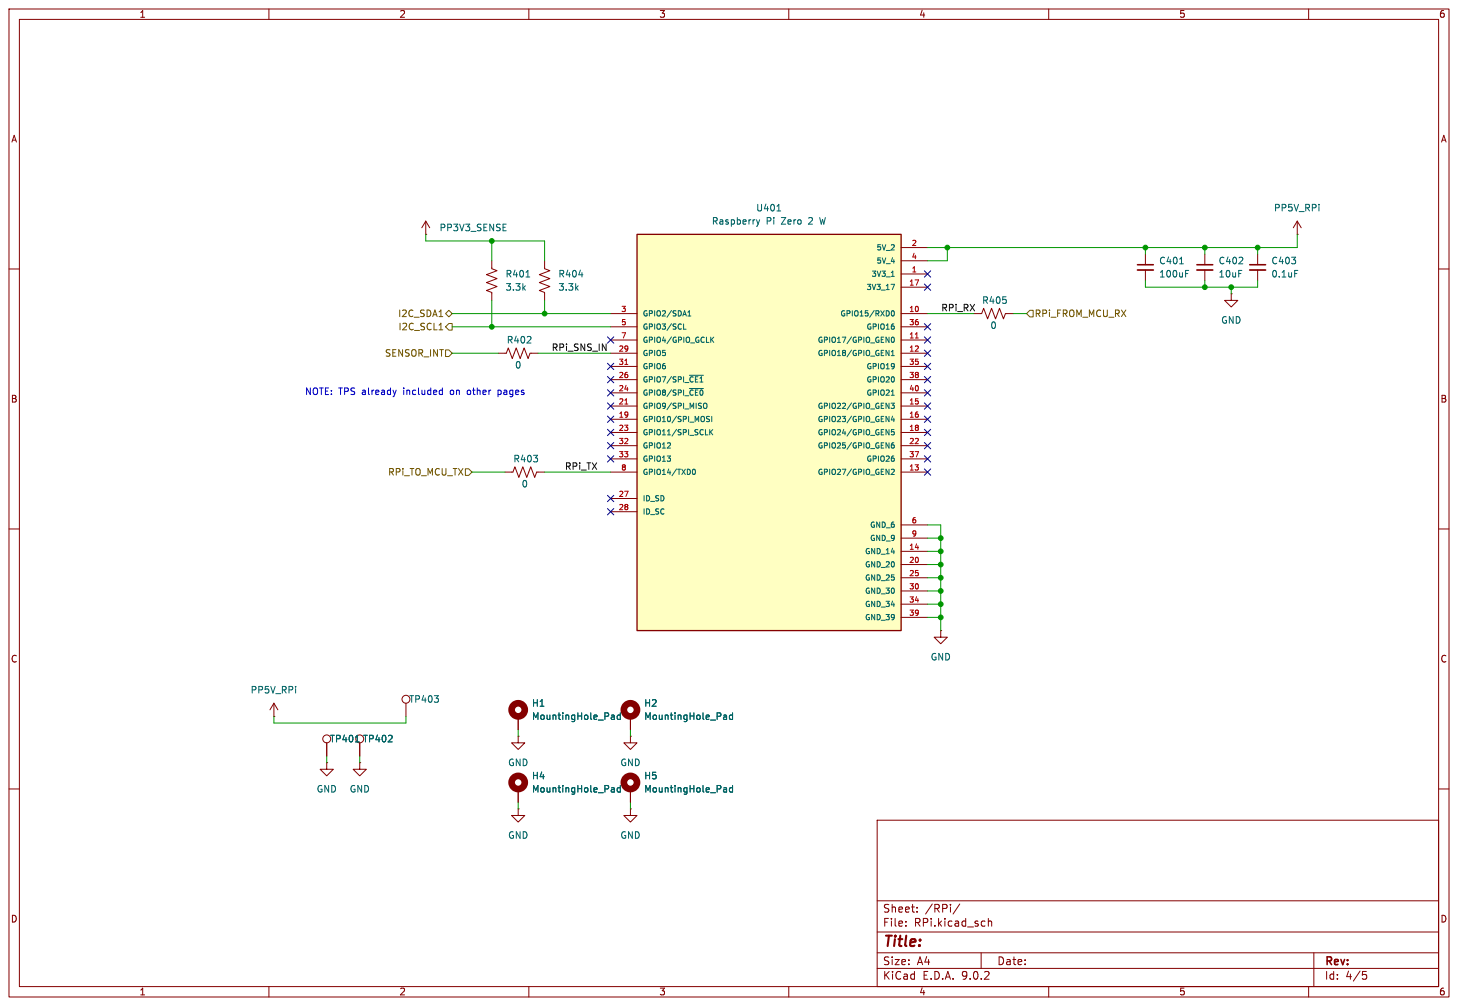
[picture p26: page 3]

Id: 4/5 Title: File: RPi.kicad_sch Sheet: /RPi/

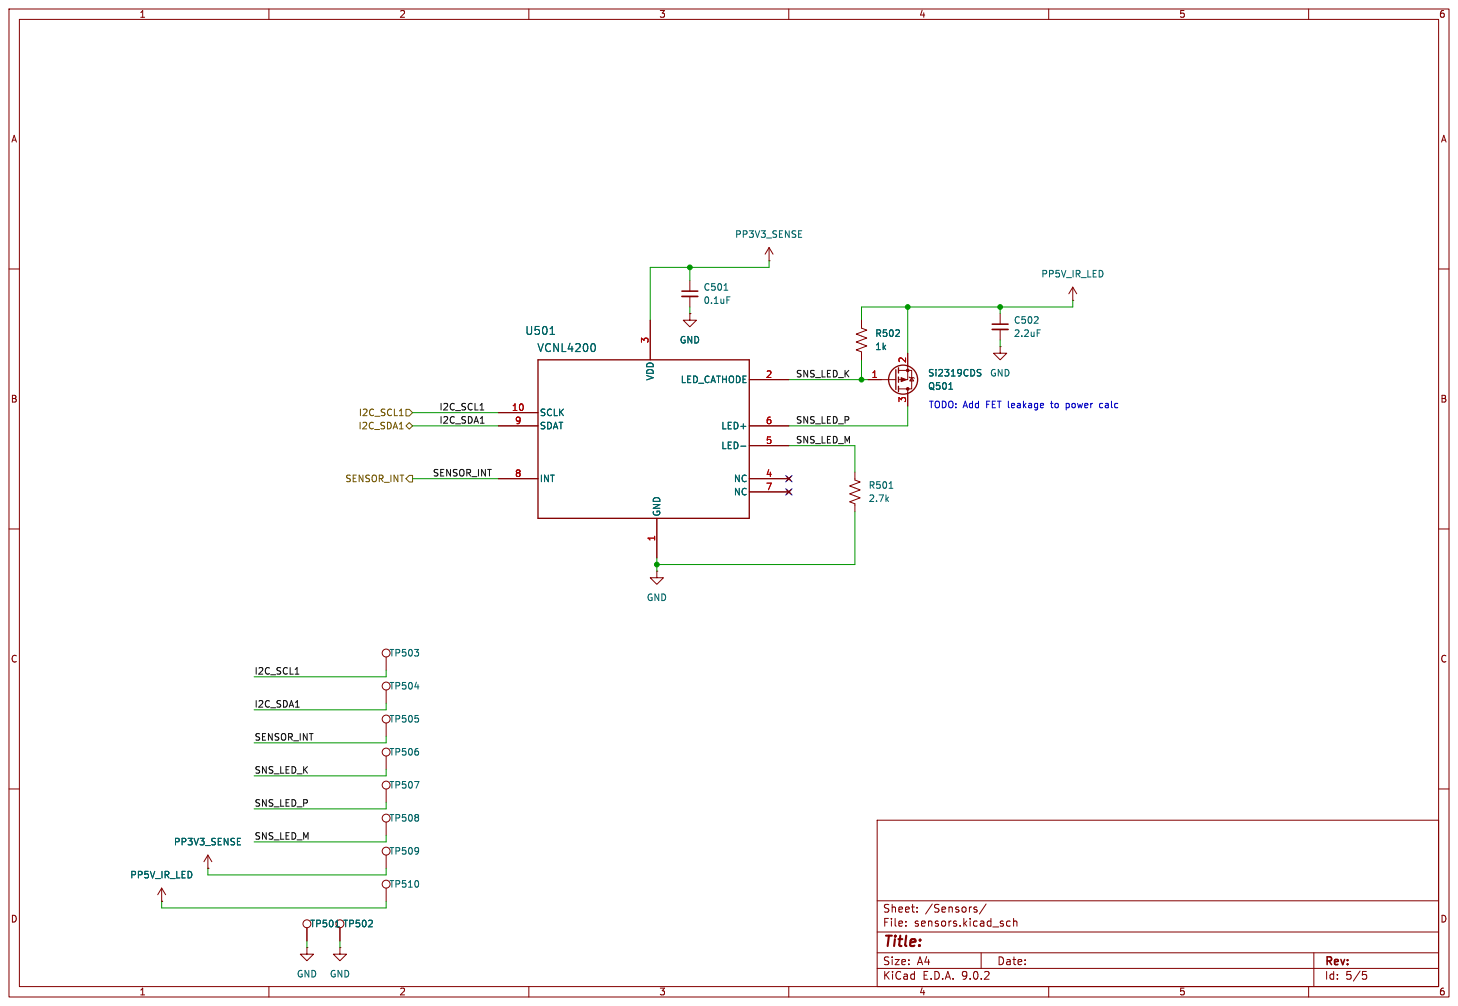
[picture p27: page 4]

TODO: Add FET leakage to power calc R502

Id: 5/5 Title: File: sensors.kicad_sch Sheet: /Sensors/

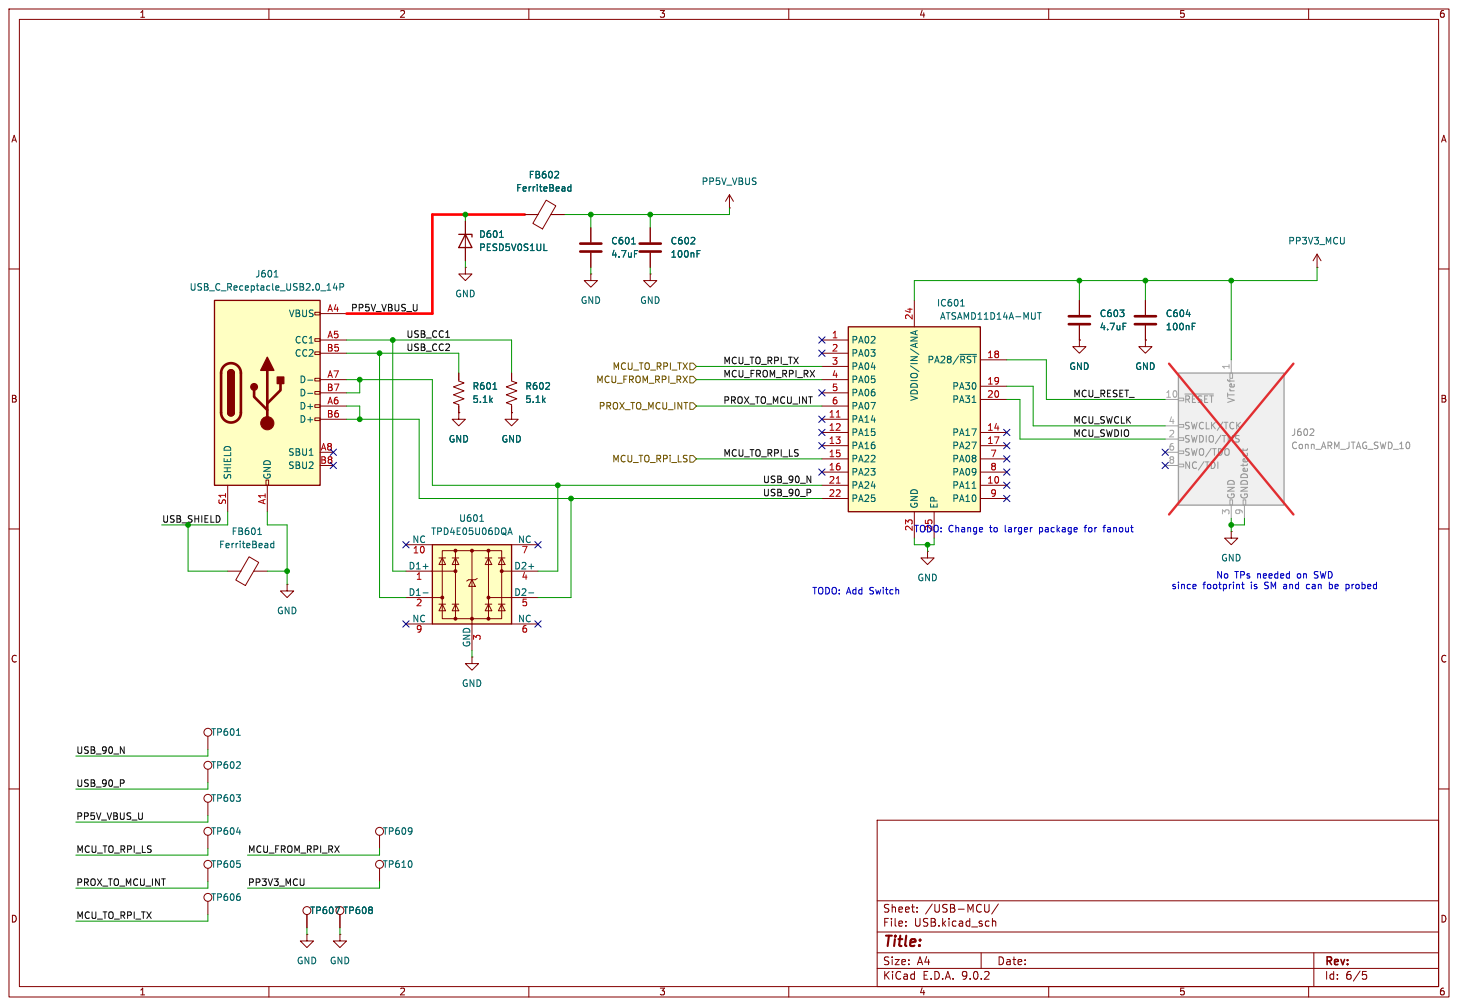
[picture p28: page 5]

3 ~{RESET} 10 SWCLK/TCK 4 SWDIO/TMS 2 SWO/TDO 6 NC/TDI 8

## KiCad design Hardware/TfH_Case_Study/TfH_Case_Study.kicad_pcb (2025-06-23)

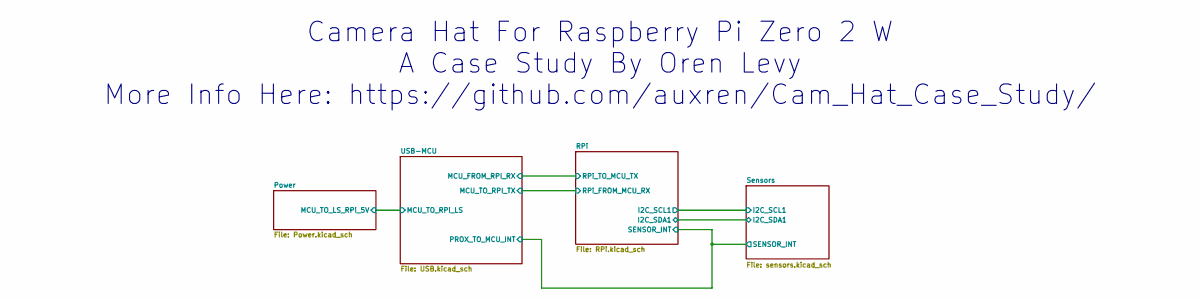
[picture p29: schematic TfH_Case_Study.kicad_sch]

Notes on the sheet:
Camera Hat For Raspberry Pi Zero 2 W A Case Study By Oren Levy More Info Here: https://github.com/auxren/Cam_Hat_Case_Study/

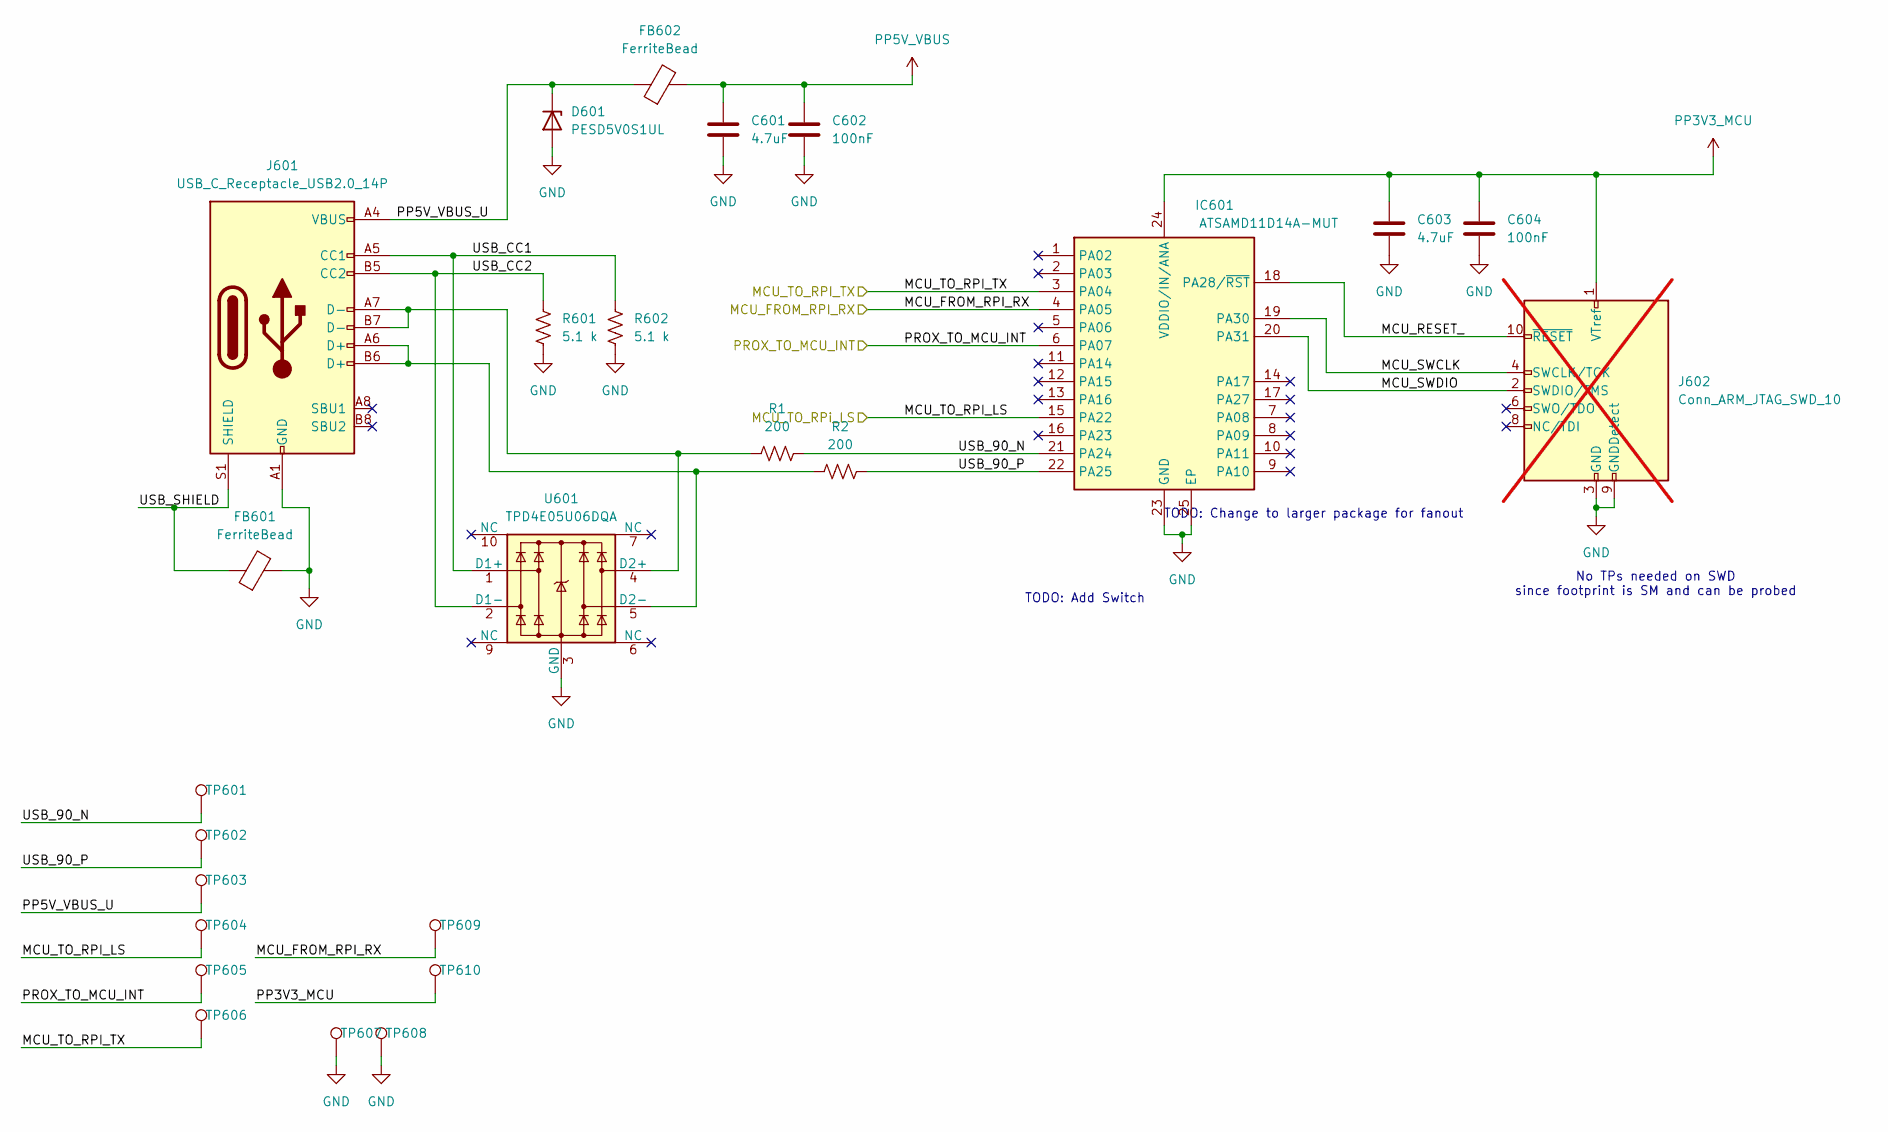
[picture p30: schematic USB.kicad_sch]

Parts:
C601, C603: 4.7uF; C_0402_1005Metric
C602, C604: 100nF; C_0402_1005Metric
D601: PESD5V0S1UL; D_SOD-882
FB601, FB602: FerriteBead; C_0402_1005Metric
IC601: ATSAMD11D14A-MUT; QFN50P400X400X90-25N-D; Mouser Part Number 556-ATSAMD11D14A-MUT
J601: USB_C_Receptacle_USB2.0_14P; USB_C_Receptacle_GCT_USB4105-xx-A_16P_TopMnt_Horizontal
J602: Conn_ARM_JTAG_SWD_10; PinHeader_2x05_P1.00mm_Vertical_SMD; not fitted
R1, R2: 200; R_0402_1005Metric
R601, R602: 5.1 k; R_0402_1005Metric
TP601, TP602, TP603, TP604, TP605, TP606, TP607, TP608, TP609, TP610: TestPoint; TestPoint_Pad_D1.5mm
U601: TPD4E05U06DQA; USON-10_2.5x1.0mm_P0.5mm

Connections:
/Sensors/SENSOR_INT: IC601.6 (PA07), TP605.1; also elsewhere on the board
/USB-MCU/MCU_FROM_RPI_RX: IC601.4 (PA05), TP609.1; also elsewhere on the board
/USB-MCU/MCU_RESET_: IC601.18 (PA28/~RST), J602.10 (~RESET)
/USB-MCU/MCU_SWCLK: IC601.19 (PA30), J602.4 (SWCLK/TCK)
/USB-MCU/MCU_SWDIO: IC601.20 (PA31), J602.2 (SWDIO/TMS)
/USB-MCU/MCU_TO_RPI_LS: IC601.15 (PA22), TP604.1; also elsewhere on the board
/USB-MCU/MCU_TO_RPI_TX: IC601.3 (PA04), TP606.1; also elsewhere on the board
/USB-MCU/PP5V_VBUS_U: D601.1 (K), FB602.1, J601.A4 (VBUS), J601.A9 (VBUS), J601.B4 (VBUS), J601.B9 (VBUS), TP603.1
/USB-MCU/USB_CC1: J601.A5 (CC1), R602.1, U601.1 (D1+)
/USB-MCU/USB_CC2: J601.B5 (CC2), R601.1, U601.2 (D1-)
/USB-MCU/USB_SHIELD: FB601.1, J601.S1 (SHIELD)
GND: C601.2, C602.2, C603.2, C604.2, D601.2 (A), FB601.2, IC601.23 (GND), IC601.25 (EP), J601.A1 (GND), J601.A12 (GND), J601.B1 (GND), J601.B12 (GND), J602.3 (GND), J602.5 (GND), J602.9 (GNDDetect), R601.2, R602.2, TP607.1, TP608.1, U601.3 (GND), U601.8 (GND); also elsewhere on the board
PP3V3_MCU: C603.1, C604.1, IC601.24 (VDDIO/IN/ANA), J602.1 (VTref), TP610.1; also elsewhere on the board
PP5V_VBUS: C601.1, C602.1, FB602.2; also elsewhere on the board

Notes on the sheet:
No TPs needed on SWD since footprint is SM and can be probed
TODO: Change to larger package for fanout
TODO: Add Switch

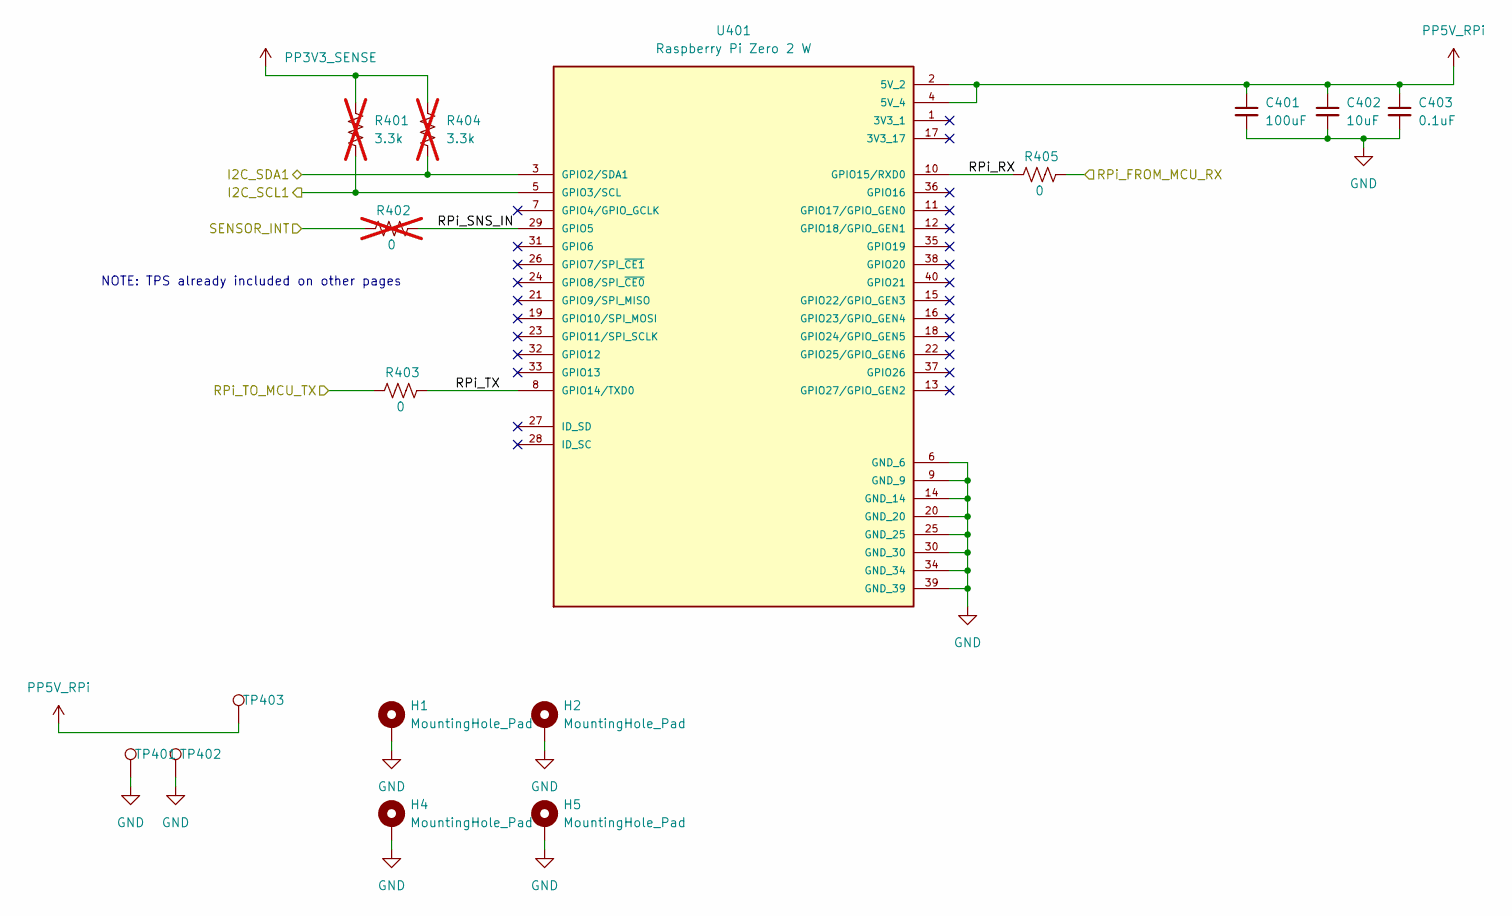
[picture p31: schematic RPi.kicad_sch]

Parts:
C401: 100uF; C_0603_1608Metric
C402: 10uF; C_0603_1608Metric
C403: 0.1uF; C_0402_1005Metric
H1, H2, H4, H5: MountingHole_Pad; MountingHole_3.2mm_M3_DIN965_Pad
R401, R404: 3.3k; C_0402_1005Metric; not fitted
R402: 0; C_0402_1005Metric; not fitted
R403, R405: 0; C_0402_1005Metric
TP401, TP402, TP403: TestPoint; TestPoint_Pad_D1.5mm
U401: Raspberry Pi Zero 2 W; PinHeader_2x20_P2.54mm_Vertical; PARTREV April 2024

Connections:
/RPi/RPi_RX: R405.1, U401.10 (GPIO15/RXD0)
/RPi/RPi_SNS_IN: R402.2, U401.29 (GPIO5)
/RPi/RPi_TX: R403.2, U401.8 (GPIO14/TXD0)
/Sensors/I2C_SCL1: R401.2, U401.5 (GPIO3/SCL); also elsewhere on the board
/Sensors/I2C_SDA1: R404.2, U401.3 (GPIO2/SDA1); also elsewhere on the board
/Sensors/SENSOR_INT: R402.1; also elsewhere on the board
/USB-MCU/MCU_FROM_RPI_RX: R403.1; also elsewhere on the board
/USB-MCU/MCU_TO_RPI_TX: R405.2; also elsewhere on the board
GND: C401.2, C402.2, C403.2, H1.1, H2.1, H4.1, H5.1, TP401.1, TP402.1, U401.6 (GND_6), U401.9 (GND_9), U401.14 (GND_14), U401.20 (GND_20), U401.25 (GND_25), U401.30 (GND_30), U401.34 (GND_34), U401.39 (GND_39); also elsewhere on the board
PP3V3_SENSE: R401.1, R404.1; also elsewhere on the board
PP5V_RPi: C401.1, C402.1, C403.1, TP403.1, U401.2 (5V_2), U401.4 (5V_4); also elsewhere on the board

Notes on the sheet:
NOTE: TPS already included on other pages

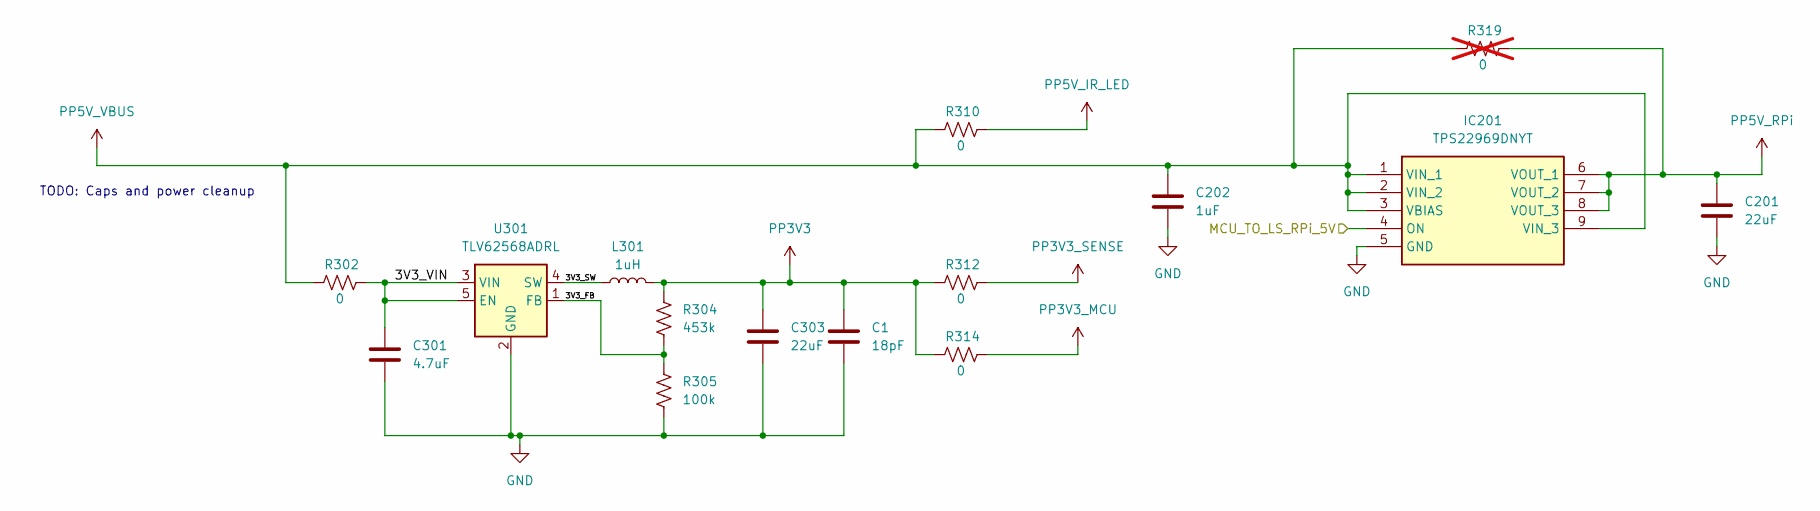
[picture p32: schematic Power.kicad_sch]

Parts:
C1: 18pF; C_0402_1005Metric
C201, C303: 22uF; C_0402_1005Metric
C202: 1uF; C_0402_1005Metric
C301: 4.7uF; C_0402_1005Metric
IC201: TPS22969DNYT; Mouser Part Number 595-TPS22969DNYT
L301: 1uH; C_0402_1005Metric
R302, R310, R312, R314: 0; C_0402_1005Metric
R304: 453k; C_0402_1005Metric
R305: 100k; C_0402_1005Metric
R319: 0; C_0402_1005Metric; not fitted
U301: TLV62568ADRL; SOT-563

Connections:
/Power/3V3_FB: R304.2, R305.1, U301.1 (FB)
/Power/3V3_SW: L301.1, U301.4 (SW)
/Power/3V3_VIN: C301.1, R302.2, U301.3 (VIN), U301.5 (EN)
/USB-MCU/MCU_TO_RPI_LS: IC201.4 (ON); also elsewhere on the board
GND: C1.2, C201.2, C202.2, C301.2, C303.2, IC201.5 (GND), R305.2, U301.2 (GND); also elsewhere on the board
PP3V3: C1.1, C303.1, L301.2, R304.1, R312.1, R314.1
PP3V3_MCU: R314.2; also elsewhere on the board
PP3V3_SENSE: R312.2; also elsewhere on the board
PP5V_IR_LED: R310.2; also elsewhere on the board
PP5V_RPi: C201.1, IC201.6 (VOUT_1), IC201.7 (VOUT_2), IC201.8 (VOUT_3), R319.2; also elsewhere on the board
PP5V_VBUS: C202.1, IC201.1 (VIN_1), IC201.2 (VIN_2), IC201.3 (VBIAS), IC201.9 (VIN_3), R302.1, R310.1, R319.1; also elsewhere on the board

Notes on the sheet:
TODO: Caps and power cleanup

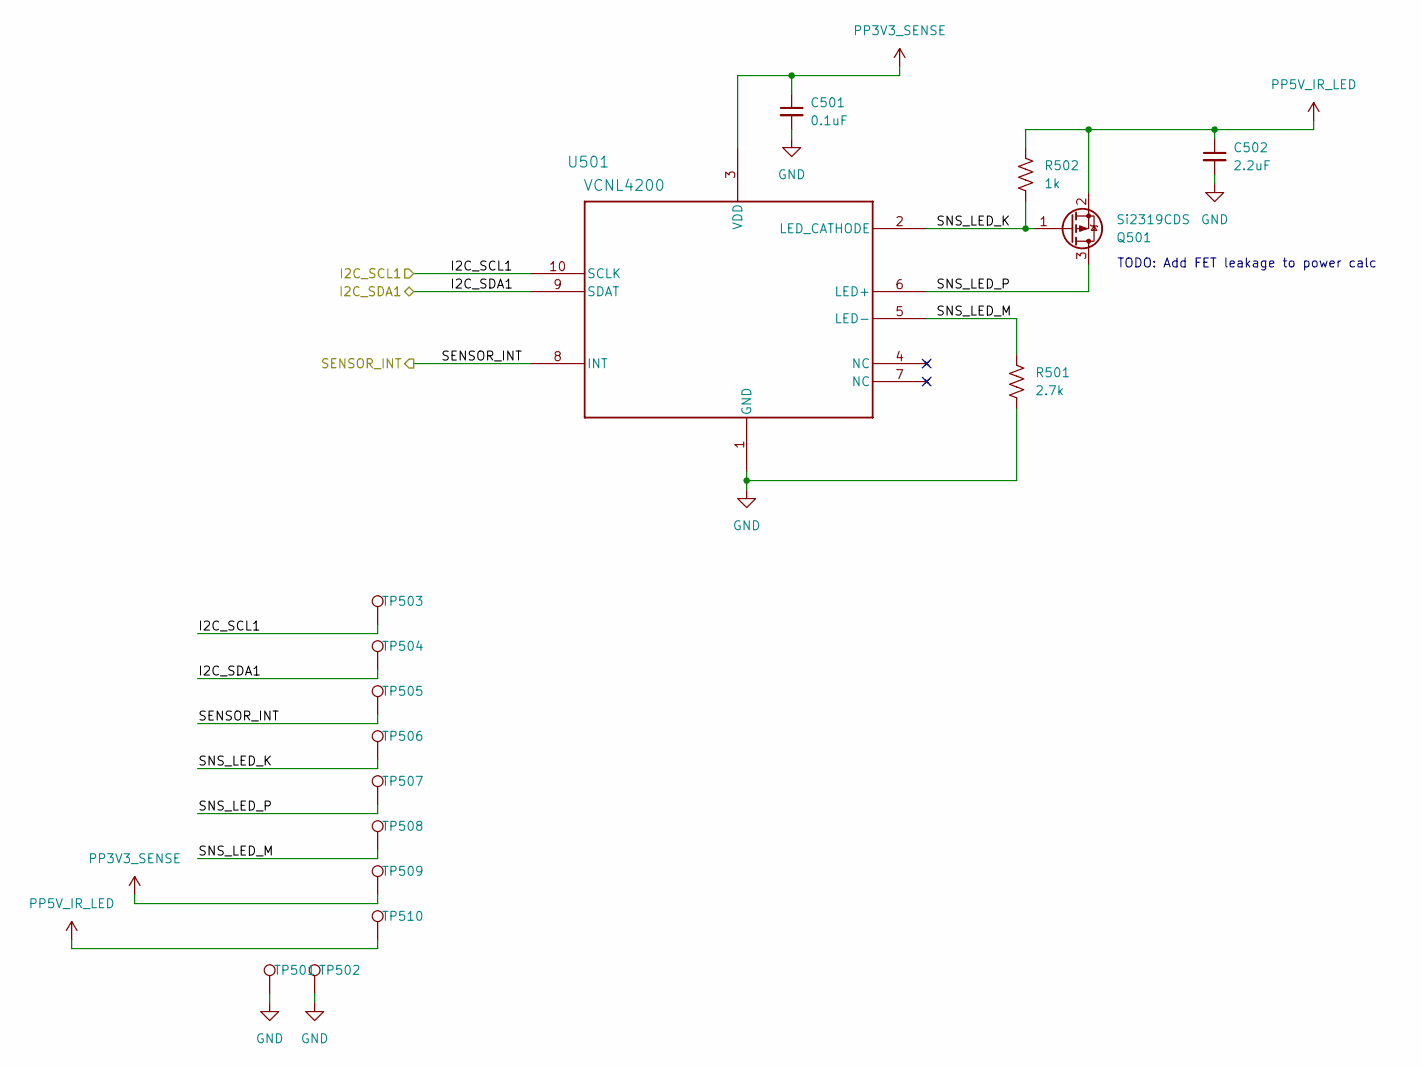
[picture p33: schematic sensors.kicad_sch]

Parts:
C501: 0.1uF; C_0402_1005Metric
C502: 2.2uF; C_0402_1005Metric
Q501: Si2319CDS; SOT-23
R501: 2.7k; R_0402_1005Metric
R502: 1k; R_0402_1005Metric
TP501, TP502, TP503, TP504, TP505, TP506, TP507, TP508, TP509, TP510: TestPoint; TestPoint_Pad_D1.5mm
U501: VCNL4200; SMT_L4200_VIS

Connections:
/Sensors/I2C_SCL1: TP503.1, U501.10 (SCLK); also elsewhere on the board
/Sensors/I2C_SDA1: TP504.1, U501.9 (SDAT); also elsewhere on the board
/Sensors/SENSOR_INT: TP505.1, U501.8 (INT); also elsewhere on the board
/Sensors/SNS_LED_K: Q501.1 (G), R502.2, TP506.1, U501.2 (LED_CATHODE)
/Sensors/SNS_LED_M: R501.1, TP508.1, U501.5 (LED-)
/Sensors/SNS_LED_P: Q501.3 (D), TP507.1, U501.6 (LED+)
GND: C501.2, C502.2, R501.2, TP501.1, TP502.1, U501.1 (GND); also elsewhere on the board
PP3V3_SENSE: C501.1, TP509.1, U501.3 (VDD); also elsewhere on the board
PP5V_IR_LED: C502.1, Q501.2 (S), R502.1, TP510.1; also elsewhere on the board

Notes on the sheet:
TODO: Add FET leakage to power calc

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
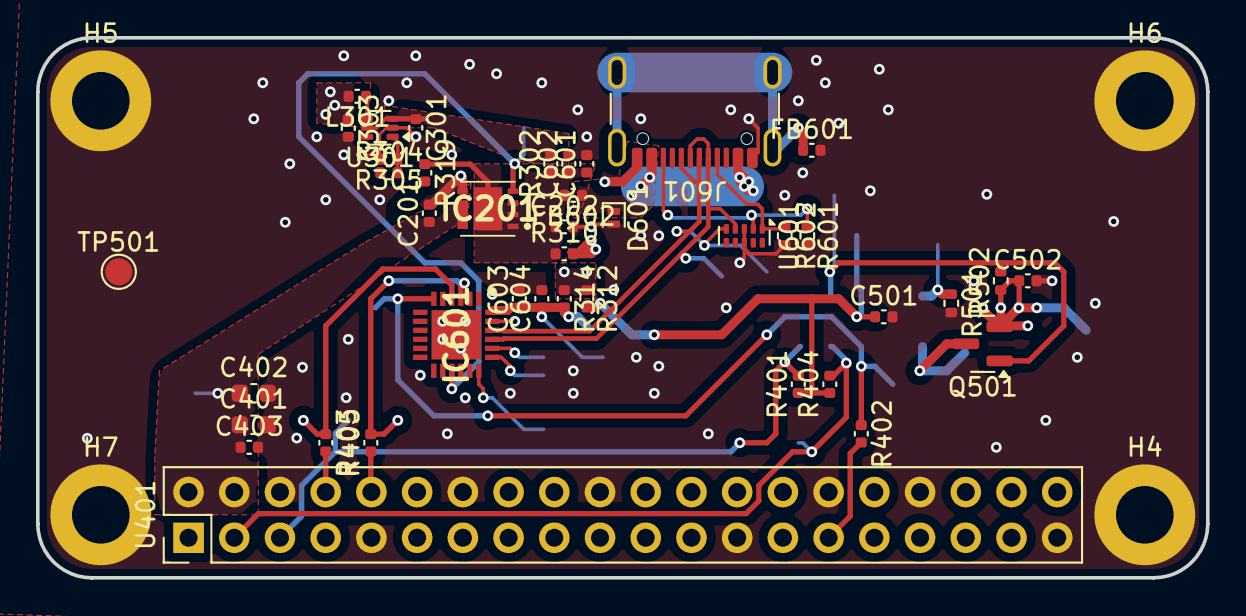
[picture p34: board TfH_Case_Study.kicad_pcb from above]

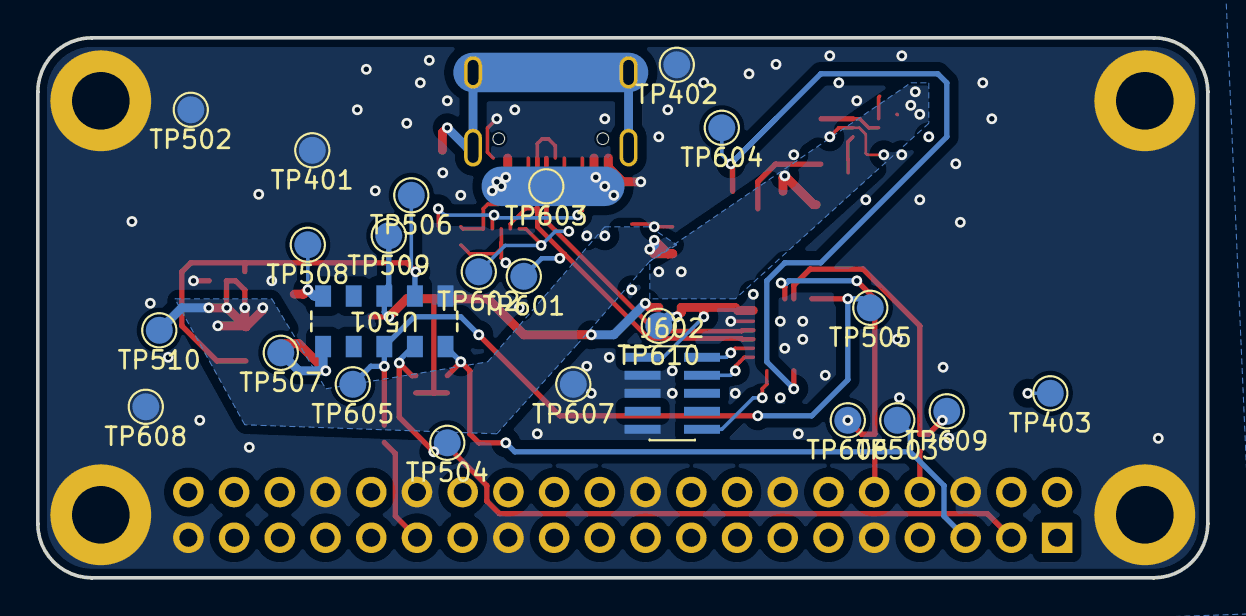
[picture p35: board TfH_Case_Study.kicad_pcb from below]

Board: 2 copper layers, 65.0 x 30.0 mm, 69 parts (24 on the bottom side), 31 nets.

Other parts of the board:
H6, H7: MountingHole_Pad; MountingHole_3.2mm_M3_DIN965_Pad

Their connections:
GND: H6.1, H7.1; also elsewhere on the board

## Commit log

2025-06-09 Initial Commit
    Setting Up Files and Folder Structures
    [TfH_Case_Study.kicad_pcb, TfH_Case_Study.kicad_sch]
2025-06-10 Daily Checkin - Schematic In progress
    Camera and Sensor pages nearly done
    [Camera.kicad_sch, DF40C-30DP-0.4V_51_.stp, EDI2CAP.CFG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]
2025-06-10 Power Tracker Added
    Added components to power schematic page
    [Camera.kicad_sch, Power.kicad_sch, RPi.kicad_sch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]
2025-06-11 Placement Started
    Lots of TODOs in Schematic
    Started placement
    [Camera.kicad_sch, CameraV1.step, CapHat v2.dxf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]
2025-06-11 Before Finding The Eagle Board
    [ATSAMD11D14A-MUT.stp, Camera.kicad_sch, EDI2CAP.CFG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]
2025-06-12 Pencils Down For PCBA
    [CameraModuleOnEagle.step, CapHatSTEPV1.step, EDI2CAP.CFG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]
2025-06-12 Updated Documentation
    [Cam_Hat_Case_Study_Model.STEP, CameraModuleOnEagle.step, CameraV1.step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]
2025-06-12 BOM Not Showing Up Fix?
2025-06-12 GitIgnore Fix
    [Cam_Hat_Case_Study_PCB_Assembly_BOM.csv, TfH_Case_Study.csv]
2025-06-23 Cleanup And Post Final
    Done with this project
    [Power.kicad_sch, RPi.kicad_sch, TfH_Case_Study.kicad_pcb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]
